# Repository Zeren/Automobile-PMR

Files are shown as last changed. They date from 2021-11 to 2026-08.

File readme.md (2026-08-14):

# SDR PMR Transceiver – Design Description (HW rev 10)

SDR transceiver for PMR446, shared channels per VO-R/16/05.2020-6 and the 70 cm amateur band. STM32H725RGV6 processes the I/Q stream from the SX1255 and generates the remodulated signal for transmit. Primary modulation is FM; SSB is a planned extension. Prepared expansion port for a CB (26.965–27.405 MHz) module on J16.

* * *

## 1. System Architecture

```
Antenna (J4 MCX) ── LPF (TX harmonics / RX pre-filter)
                  │
                  U7  (SKY13330, FILTER_TUNE, PC5) ── tune port J3
                  │
                  U10 (SKY13330, TX/RX, PC1)
                  │      RX:
                  U19 (LNA-in SW) ── U20 PGA-103+ (LNA) ── U21 (LNA-out SW)
                  │      └─────────── bypass path ───────────┘
                  U8/U9 (BPF select, RX_BAND PC4 + inverter Q4)
                  │      ├─ external BPF PMR/shared  (J12/J13, RX only)
                  │      └─ external BPF 70 cm       (J10/J11, RX only)
                  │
SX1255 (U6) ◄── I2S (Mode B2, I/Q) + SPI6 (register map) ──► STM32H725 (U15)
TAC5142 (U11 codec) ◄── I2S2 (32 bit, target/slave) ──► STM32H725 (U15)
CB module (J16) ◄── I2S3 (32 bit, master) + I2C1 + CB_nIRQ + CB_nRESET
```

TX path: STM32 (I2S1) → SX1255 (I/Q mod, synthesizer, TX front-end) → balun U5 (NCS1-521+) → π attenuator (82R/91R/91R) → PA U4 (GRF5504) → output LPF → U7/U10 switches → J4.

## 2. RF Front-End (Semtech SX1255, U6)

*   Zero-IF I/Q transceiver, internal 3 V rails VR_PA / VR_ANA1 / VR_ANA2 / VR_DIG with 1 µF decoupling each.
    
*   TX: differential RF_ON/RF_OP through balun U5 into the PA drive network. Max +7 dBm saturated.
    
*   RX: single-ended RF_IN via switch matrix and external BPF. NF typ. 4.5 dB at max LNA gain; IIP3 −23 dBm (max gain) … +20 dBm (min gain); max RF input 0 dBm operating.
    
*   Consumption: RX 18–25 mA, TX 60–90 mA from +3V3_RF.

### 2.1 Clock Domain 32 MHz

*   **TCXO1 = ATX-H13-F-32.000MHz-F25-T** (CMOS output, ±2 ppm tolerance, ±2.5 ppm over −40…+85 °C, aging ±1 ppm/yr). Worst-case error ≈ ±4.9 ppm → ±2.2 kHz @ 446 MHz. Pin 1 (EN) via R137 0R → +3V3_CLOCK (fitted); R138 0R → GND (DNP) allows Hi-Z mode for external reference operation. Powered from dedicated LDO U22 (+3V3_CLOCK).
    
*   Fanout buffer U23 (74AC04MTCX), each output with its own 30R series resistor:
    *   1Y → R130 → **J16-10** (32 MHz for the CB module),
        
    *   2Y → R132 → **PH0-OSC_IN** (MCU HSE bypass),
        
    *   3Y → R134 → **PC9** (I2S_CKIN, kernel clock of I2S1/I2S2/SPI123),
        
    *   4Y → R135 → R50/R51 1k/1k divider → **XTB** of SX1255 (~1.65 Vpp, limit 1.8 Vpp).
        
*   **External reference option (DNP group):** J17 (MMCX) → R133 50R termination → C106 → clamp D16 (BAT64) → U24 (TP74AUP1G14C5 Schmitt, DNP) → R131 → U23 inputs. For external reference mode: remove R137 (TCXO1 EN → Hi-Z) and populate the DNP group.
    
*   PLL1: 32 MHz /3 ×51 → **544 MHz** SYSCLK; HCLK 272 MHz, APB 136 MHz.
    
*   USB 48 MHz from PLL3Q: 32 MHz /6 ×90 /10 – no HSI48/CRS needed.

### 2.2 I2S1: SX1255 ↔ STM32 (Mode B2)

| Block | Parameter | Value | Note |
| --- | --- | --- | --- |
| SX1255 | I/Q mode | **Mode B2** (`IISM=10`) | I/Q multiplexed on one data line; chip is master of CLK and WS |
|  | CLK_OUT divider (`iism_clk_div`) | **48** | 32 MHz / 48 = **666.67 kHz** = BCLK |
|  | Decimation R | **1536** (MANT=8, m=1, n=6) | fs = 32 MHz / 1536 = **20.8333 kHz** |
|  | Sample width | **16 bit / channel** | frame = 32 BCLK (16 I + 16 Q) |
|  | WS output | DIO2 (pin 23) | WS=0 → I, WS=1 → Q (Philips convention) |
| STM32 I2S1 | Role | **Slave, full-duplex** | SX1255 is clock master |
|  | Standard / format | I2S Philips, **16 bit** | main.c: `I2S_MODE_SLAVE_FULLDUPLEX`, `I2S_DATAFORMAT_16B`, 20833 Hz |
|  | Kernel clock | `i2s_ckin` (PC9, 32 MHz) | RCC mux `SPI123CLKSOURCE_PIN` |

Wiring: `I_OUT` (pin 15, RX data out) → R43/R89 → **PA6** (I2S1_SDI); MCU **PA7** (I2S1_SDO) → pin 13 `I_IN` (IQ_IN in B2); `CLK_OUT` (pin 10) → R42 → **PA5** (I2S1_CK); DIO2 (WS) → R47 → **PA4** (I2S1_WS). Frequency step: FSTEP = 32 MHz / 2^20 = **30.52 Hz** (FRF registers must be recomputed for 32 MHz reference).

### 2.3 SPI6 – SX1255 Register Interface

| CubeMX parameter | Setting | Note |
| --- | --- | --- |
| Mode | Full-Duplex Master | SCK PB12… (see GPIO table), MISO PB4, MOSI PB5, SCK PC12 |
| NSS | Soft (GPIO) | **PB3** `SPI6_nCS`, held low across whole BURST transaction |
| Data / First bit | 8 bit, MSB first | per SX1255 DS |
| CPOL / CPHA | Low / 1 Edge | Mode 0 |
| Baud | **8.5 MHz** | 136 MHz APB /16; SX1255 limit ≤10 MHz |

Frame format: first byte = `wnr` (bit7, 1=write) + address A[6:0]. On read, MISO is High-Z during the address byte; on write, MISO returns the previous register content.

## 3. Baseband & DSP (STM32H725RGV6)

*   I/Q from SX1255 via I2S1 slave; **CORDIC** for phase/amplitude demodulation (Q1.15 pairs in one 32-bit WDATA word); **FMAC** for channel FIR/IIR filtering.
    
*   Core supply: internal Direct SMPS (L14 2R2 + VCAP bank), `PWR_DIRECT_SMPS_SUPPLY`, VOS0.
    
*   Firmware: C stack (HAL + STM32 USB Device Library).

## 4. Audio Chain (TAC5142IRGER, U11)

Codec on I2S2 as **target/slave** (MCU master), synchronised with the radio sampling domain. Configuration is hardware-latched on MD0–MD5 at power-up (all six pins via 0R to GND; the IOVDD side is DNP).
| Pin | Setting | Meaning |
| --- | --- | --- |
| MD0 = 0 | **Target I2S mode** | slave; BCLK/FSYNC from MCU |
| MD1/MD2 = 0/0 | AVDD 3.3 V, **32 bit**, linear-phase filters |  |
| MD3 = 0 | HPF ≈ 1 Hz, quick charge off |  |
| MD4/MD5 = 0/0 | differential AC-coupled input, differential line-out |  |

> MD pins latch at power-up; MD0 must be stable ≤2 ms after rails; changing ASI mode requires a power cycle.

### I2S2 parameters

*   Role: MCU **master** → codec target; Philips, **32 bit / 32-bit frame** (64 BCLK/frame).
    
*   fs = **20.8333 kHz**; BCLK = 32 MHz / 24 = **1.3333 MHz**; kernel = i2s_ckin.
    
*   Mapping: BCLK PB10 → U11/2; FSYNC PB12 → U11/3; MCU **PB15 (SDO) → DIN** (U11/5); codec **DOUT** (U11/4) → R57/R98 → **PB14 (SDI)**.

### Analog audio (single +30 V domain)

Audio chain U1/U12/U14 (SA5532ADR) and U13 (TPA6120A2) run on single +30 V with virtual grounds: HALF_BIAS (10k/10k divider) and HALF_BIAS_BUFFERED / HALF BIAS MIC buffered by the two halves of U14. Codec IN2 has AC coupling C57/C58 (100 nF) toward J15. Line outputs drive U12 stage → U13 (TPA6120A2, CFA, Rf = 1k, R73 = **49R9 1.5 W** series output) → C63 (**10 µF ALU 63V** DC block) → PTC F4 → J7/J8. Both TPA6120 channels powered (+LVCC/+RVCC on +30 V). Codec rails: +3V3_CODEC from U17 (LDK320).

## 5. PA Stage (GRF5504, U4)

*   Custom tune **#229 (400–500 MHz)**: gain ~40 dB, OP1dB ~33 dBm, OIP3 ~40–42 dBm, EVB NF ~5.5 dB, Iddq ~137 mA @ 5 V.
    
*   Bias resistors R37 = 3k3 (VEN1), R38 = 6k8 (VEN2) per the 5 V bias table; bias switching Q2/Q3 from PA_BIAS_ON (PC1) with external 100k pull-down.
    
*   Target operating point: **FM ≤ 33 dBm** at the connector. SSB: backoff + IMD3 measurement open (estimate −28…−30 dBc around 26 dBm/tone).

### Class-G control of the +30 V rail (TLV61047, U3)

TIM3_CH1 (PC6) PWM 25 kHz (PSC=3, ARR=2719 @ 272 MHz) is filtered (R30 91k + C29) and injected through R32 22k into the FB node. KCL at FB with VREF = 1.233 V: (VOUT − VREF)/430k + (VCTRL − VREF)/(91k + 22k) = VREF/22k → **VOUT ≈ 28.2 V @ 0 % duty … 20.4 V @ 100 % duty**, ~3 mV/LSB, linear inverse. **Firmware must clamp duty** (VREF tol. ±2 % and TPA6120/SA5532 30–33 V limits). Startup: PWM started only after rails settle.

## 6. Filters & Switch Matrix

### 6.1 Output LPF with shunt-inductor ESD protection

Series L8–L11 (19n/38n/38n/19n) + C53/C55/C56 (8p5/8p5/9p1) + **shunt inductors L12/L13 (20 nH air-core) to GND** near J4. The shunt L provides a DC/low-frequency bleed path for ESD charge instead of a diode clamp (no parasitic capacitance on the RF line; harmless at 432–450 MHz). Simulated S-parameters: **S11 < −20 dB over 432–450 MHz, IL ≤ ~0.15 dB, 2nd harmonic (860–900 MHz) −54…−58 dB**. Use air-core/wire-wound parts (no ferrite multilayer – saturation); re-tune C53 after PCB parasitics.

### 6.2 Switch truth table (SKY13330, VBATT = +3V3_RF)

| Switch | Function | CTRL (pin 7) | CTRL=1 | CTRL=0 |
| --- | --- | --- | --- | --- |
| **U10** | TX/RX path | PA_BIAS_ON (PC1) | TX (PA path) | RX |
| **U8/U9** | external BPF select | RX_BAND (PC4), inverter Q4 | 70 cm (J10/J11) | **PMR/shared (J12/J13)** |
| **U7** | antenna vs tune | FILTER_TUNE (PC5) | tune port J3 | antenna J4 |
| **U19/U21** | **LNA in/out** | **LNA ON (PC7)** | **LNA (U20) in path** | **bypass** (default after POR) |

CTRL level via 10k/22k divider ≈ **2.27 V** (valid window 1.65–2.7 V; ≤ VDD). Isolated ports are reflective-short.

### 6.3 Switchable LNA (U20 = PGA-103+)

*   Located between U10 and the BPF matrix, bypassed by U19/U21 (default bypass after POR via R123 100k pull-down on PC7).
    
*   Supply: +3V3_RF → Q8 (NX3008PBKW load switch, gate via Q9/Q10) → L16 (LQW18ANR10) + R124 1k Q-damping → U20 pin 3. Operating point ≈ 3.0–3.1 V, ~60 mA: gain ≈ 21.5 dB @ 0.4 GHz, NF ≈ 0.5 dB, P1dB ≈ +18…19 dBm, OIP3 ≈ +34 dBm.
    
*   Low-frequency stabilisation on input: C98 (100p) + L17 (330 nH) → C101 (270 pF) → R125 (120R) trap (validated in AWR; PGA-103+ is conditionally stable below ~200 MHz).
    
*   Combined RX chain NF: ~7–8 dB without LNA → ~2 dB with LNA.
    
*   **Firmware: auto-bypass by RSSI mandatory** (LNA sits before the BPF; blockers amplified). Reduce SX1255 internal LNA gain (RxLnaGain G2/G3) when external LNA active. Two RSSI calibration tables (bypass / LNA-on, ~21 dB offset).

## 7. Power Supply

| Rail | Converter | Values | Note |
| --- | --- | --- | --- |
| +26V input | J6/J7/J8, **F1 0458004.DR (4 A)**, D7 SMDJ33A | standoff 33 V | 24 V vehicle systems |
| **+5V** | U2 SIC479ED buck | 52k3/10k → 4.98 V; fSW 39k; MODE 10k; ILIMIT→VDD (4 A valley); L1 FTKB1207-6R1 | FR1 ferrite at input |
| **+30V** | U3 TLV61047 boost | 430k/22k + PWM injection (§5); L2 FTC404020S100MGCA; D4 DFLS240L | fed directly from +5 V |
| **+3V3_MCU** | U16 TLV62130 buck | 750k/240k → 3.30 V; EN=PG_5V; PG→PG_3V3; FSW=VOUT; SS 3n3; L15 2R2 | input ferrite FR3 |
| **+3V3_CODEC** | U17 LDK320 | EN=PG_5V; COUT ≈ 11 µF | ferrite FR4; codec AVDD+IOVDD |
| **+3V3_RF** | U18 LDK320 | EN=PG_5V; COUT ≈ 18 µF | ferrite FR5; SX1255 + RF switches + LNA |
| **+3V3_CLOCK** | U22 LDK320 | EN=IN (always on); COUT ≈ 13 µF | ferrite FR6; TCXO + U23 (+U24 DNP) |
| MCU core | internal SMPS | Direct SMPS, L14 2R2 + VCAP bank | PWR_DIRECT_SMPS_SUPPLY |

*   All ferrites: 742792023 (120 Ω @100 MHz, 3 A). Local ceramics at each IC per its layout guide.
    
*   Sequencing: SIC479 PGOOD → enables U3/U16/U17/U18 (PG_5V); TLV62130 PG → PG_3V3 (LED).
    
*   J16 carries **+POWER_RAIL** (26 V behind F1/TVS/FR2) with C101 = 10 µF ALU at the header.

## 8. USB (OTG HS, FS embedded PHY)

Composite device: Audio Control, AS OUT (playback, async + feedback), AS IN (record / I/Q), CDC (CAT). VBUS sensing PA9 via 10k/39k divider. USB clock: PLL3Q 48 MHz.
**Asynchronous UAC at 20.833 kHz:** declared 24 kHz nominal rate would be wrong — device works with **mostly 21 samples, sometimes 20 samples per 1 ms SOF** (average 20.833) on the IN endpoint; host-side async resampling handles the rest (same mechanism as before, recalculated for 32 MHz).

## 9. MCU Configuration (CubeMX rev)

*   PLL: HSE_BYPASS 32 MHz → M=3, N=51, P=1 → 544 MHz; HCLK 272, APB 136 MHz.
    
*   I2S1 slave FD 16 bit 20833 Hz; I2S2 master FD 32 bit; I2S3 master FD 32 bit (CB, J16).
    
*   SPI6 /16 → 8.5 MHz; kernel SPI123 = i2s_ckin (RCC mux `RCC_SPI123CLKSOURCE_PIN`).
    
*   I2C1 timing 0xA0303048 (~100 kHz @136 MHz) – external buses J15/J16.
    
*   TIM3 CH1 PC6 PWM 25 kHz for class-G; UART4 (panel), UART5 (debug: TX PB13, RX PD2).
    
*   USB: PLL3Q 48 MHz; FS embedded PHY, VBUS sensing.
    
*   Debug: **Serial Wire only** (JTAG pins reused).
    
*   Verify in generated MSP: `HAL_RCCEx_PeriphCLKConfig()` with PLL3 = 32/6/90/Q=10 for USB and SPI123 kernel = pin clock.

### GPIO map

| Signal | Pin | Type | Function |
| --- | --- | --- | --- |
| RADIO_RESET | PC0 | In/Out | SX1255 reset (OD emulation: PP high 100 µs → Hi-Z, 5 ms wait) |
| **PA_BIAS_ON** | PC1 | Out PP | 1 = TX (PA bias + U10 switch); 100k ext pull-down |
| **RX_BAND** | PC4 | Out PP | 0 = PMR/shared BPF (J12/J13), 1 = 70 cm BPF (J10/J11) |
| **FILTER_TUNE** | PC5 | Out PP | 1 = tune port J3 instead of antenna |
| **LNA ON** | PC7 | Out PP | 1 = LNA in path; 0 = bypass (POR default) |
| **MCU 30V CTRL** | PC6 | AF (TIM3_CH1) | class-G PWM 25 kHz |
| PTT_TO_MCU | PA2 | In (pull-up) | 0 = TX; debounce in FW |
| PTT_LED | PA3 | Out PP | red TX LED |
| **SPI6_nCS** | PB3 | Out PP | SX1255 NSS (manual, across BURST) |
| **CB_nIRQ** | PB8 | In EXTI falling, pull-up | CB module interrupt |
| **CB_nRESET** | PB9 | Out PP, init HIGH | CB module reset |
| I2S_CKIN | PC9 | AF input | 32 MHz kernel clock |
| SWDIO/SWCLK | PA13/PA14 | AF | programming via J5 |
| UART4 TX/RX | PA0/PA1 | AF | control panel |
| UART5 TX/RX | PB13/PD2 | AF | debug console (J5) |

## 10. Connectors

**J5 – service (53047-1010):** 1 SWDIO, 2 SWCLK, 3 NRST, 4 UART_DEBUG_TX, 5 UART_DEBUG_RX, 6 I2C_SCL, 7 I2C_SDA, 8 +5V, 9 +3V3, 10 GND.
**J16 – CB module (61301621121):** 1/2/11/12 GND, 3 I2S3_CLK, 4 I2C_SCL, 5 I2S3_DIN, 6 I2C_SDA, 7 I2S3_DOUT, 8 +5V, 9 I2S3_WS, **10 = 32 MHz clock out**, 13 CB_nIRQ, 14/16 +POWER_RAIL (26 V), 15 CB_nRESET.
**RF:** J4 antenna MCX; J3 tune port MMCX; J10/J11 external BPF 70 cm; J12/J13 external BPF PMR/shared; J17 external 32 MHz reference input (DNP option); J2 UFL (test).

### M12 connector

| M12 | Function | Wire color |
| --- | --- | --- |
| 1 | +26V | Black |
| 2 | PTT | Brown |
| 3 | Mic+ | Red |
| 4 | Mic- | Orange |
| 5 | NC | Yellow |
| 6 | Speaker | Green |
| 7 | GND | Blue |
| 8 | NC | Violet |

### R123

| Cont. |  | Cont. |  | Cont. |  |
| --- | --- | --- | --- | --- | --- |
| a1 |  | b1 | +26V (Black) | c1 |  |
| a2 |  | b2 |  | c2 | GND (Blue) |
| a3–a8 |  | b3–b9 |  | c3–c8 |  |
| a9 |  | b9 |  | c9 | PTT (Brown) |
| a0 | Speaker (Green) | b0 | MIC+ (Red) | c0 | MIC- (Orange) |

### R124 A-2

| Cont. |  | Cont. |  |
| --- | --- | --- | --- |
| a1 | A-1 R112 MIC+ | b1 | A-1 R123 MIC+ |
| a2 | A-1 R112 MIC- | b2 | A-1 R123 MIC- |
| a3 | Tangenta PTT | b3 | Tangenta MIC+ |
| a4 | Intercom MIC to PA | b4 | Tangenta MIC- |
| a5 | GND | b5 | A-1 R112 Speaker |
| a6 | +22V for A-2..A-5 | b6 | A-1 R112 PTT |
| a7 | Tangenta Speaker | b7 | A-1 R123 Speaker |
| a8 | Intercom Speaker | b8 | A-1 R123 PTT |

## PMR 446 Technical Specification

*   Transmit Power 500 mW ERP
    
*   Bandwidth 12.5 kHz
    
*   Antenna fixed, non removable
    
*   Frequency Modulation and digital modes
    
*   User Separation CTCSS, DCS, digital signalling
    
*   Frequencies (Simplex TX=RX)

## 11. Open Items / Bench Checklist

1.  Verify amplitudes after assembly: ~3.3 Vpp CMOS at U23 inputs, ~1.65 Vpp at XTB (U6-8).
    
2.  External reference mode (if used): input at U24 must provide ≥ ~1.6 Vpp to clear the TP74AUP1G14C5 thresholds; rework = remove R137, populate U24 + J17/R133/D16 group.
    
3.  SSB: measure GRF5504 IMD3 on the devboard, set operating backoff.
    
4.  PMR446 "fixed antenna" requirement vs J4 connector – documentation decision.
    
5.  MICBIAS (U11-14) unused with dynamic microphone – leave with local 1 µF only.
    
6.  AWR re-check of LPF with real air-coil models (DCR/SRF) and sweep to ≥1.4 GHz (3rd harmonic).
    
7.  LNA stability/NF verification with the complete RX cascade on the prototype.

## Layout Checklist (for the frozen schematic)

*   GRF5504 power pad: multiple 8-mil vias per eval board guidance; TPA6120 PowerPAD soldered with vias; TAC5142 thermal pad grounded; SKY13330 exposed pads low-impedance GND.
    
*   SIC479 input/PGND loops, BOOT cap placement, AGND single-point, TLV61047 SW node minimal, TLV62130 VOS tapped at C_out.
    
*   LDO input/output caps at pins (COUT ≤ 22 µF per rail), ferrites directly in input paths.
    
*   Clock domain (TCXO1 → R136 → U23 → fanout) short, away from USB D±, audio and J16/J17; no 32 MHz trace over GND plane splits.
    
*   +26V/fuse/ESD at board edge near J6–J8; J16 +26V branch traces sized ≥3 A.

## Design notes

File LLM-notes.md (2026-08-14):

# How to get HW specification

Proveď destilaci celého našeho návrhu hardwaru a vygeneruj strojově čitelný "Hardware Specification Manifest" ve formátu YAML. Udělej ho jako raw, nebo jako přílohu (attachment).
Tento dokument bude sloužit jako jediný vstup pro vývoj embedded firmwaru. Zcela ignoruj proces návrhu, BOM, pasivní součástky (pokud neovlivňují logiku) a fyzický layout. Soustřeď se výhradně na to, co musí znát programátor (C, STM HAL). Ještě můžeš doporučit nastavení DMA kanálů (především I2S, SPI, UART). Potom je ještě zvlášť napiš jaké mám kde nastavit v SMT32cubeMX.
Při generování dodržuj tuto strukturu:
1. mcu_config: Přesný typ MCU, frekvence jádra, zdroj hodin (HSE/HSI).
2. pinmap: Seznam všech využitých pinů. Formát: [Pin, Název signálu, Směr/Typ, Pull-up/down, Alternate Function (pokud jde např. o STM32 AF), Aktivní úroveň (High/Low)].
3. peripherals: Konfigurace periferií (např. I2C adresy slave zařízení na sběrnici, rychlost SPI, baudrate UARTu, přiřazení DMA kanálů).
4. power_and_reset: Sekvence zapínání periferií (pokud existují povolovací EN piny), časy potřebné pro ustálení napětí, konfigurace externího watchdogu.
5. interrupts: Požadovaná hardwarová přerušení a jejich priority.
6. quirks: Hardwarová specifika (např. "LED svítí při log. 0", "Senzor XY vyžaduje po startu 10 ms delay", "CS pin pro SPI flash má externí pull-up").
Vrať POUZE čistý kód ve formátu YAML. Nepřidávej žádný úvodní ani závěrečný text, žádné vysvětlování. Výstup bude anglicky.

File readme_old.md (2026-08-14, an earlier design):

# PMR radio for R124

# Connection to R124

## Connection in R124 A-1
### Connection as R112. 

| Cont. | | Cont. | | Cont. | |
|---|---|---|---|---|---|
| a1 | | b1 | +26V <br/> Black | c1 | |
| a2 | | b2 | Speaker <br/> Green | c2 | GND <br/> Blue |
| a3 | PTT<br/> Brown | b3 | MIC- <br/>Orange | c3 | MIC+ <br/> Red |
| a4 | | b4 | | c4 | |
| a5 | | b5 | | c5 | |
| a6 | | b6 | | c6 | |
| a7 | | b7 | | c7 | |
| a8 | | b8 | | c8 | |
| a9 | | b9 | | c9 | |
| a0 | | b0 | | c0 | |

### Connection as R123. 

| Cont. | | Cont. | | Cont. | |
|---|---|---|---|---|---|
| a1 | | b1 | +26V <br/> Black | c1 | |
| a2 | | b2 | | c2 | GND <br/> Blue |
| a3 | | b3 | | c3 | |
| a4 | | b4 | | c4 | |
| a5 | | b5 | | c5 | |
| a6 | | b6 | | c6 | |
| a7 | | b7 | | c7 | |
| a8 | | b8 | | c8 | |
| a9 | | b9 | | c9 | PTT<br/> Brown |
| a0 | Speaker <br/> Green | b0 | MIC+ <br/> Red | c0 | MIC- <br/>Orange |

## M12 Connector

| M12 | Function | Wire color |
|-----|---|---|
| 1 | +26V | Black |
| 2 | PTT | Brown |
| 3 | Mic+ | Red |
| 4 | Mic- | Orange |
| 5 | NC | Yellow |
| 6 | Speaker  | Green |
| 7 | GND | Blue |
| 8 | NC | Violet |

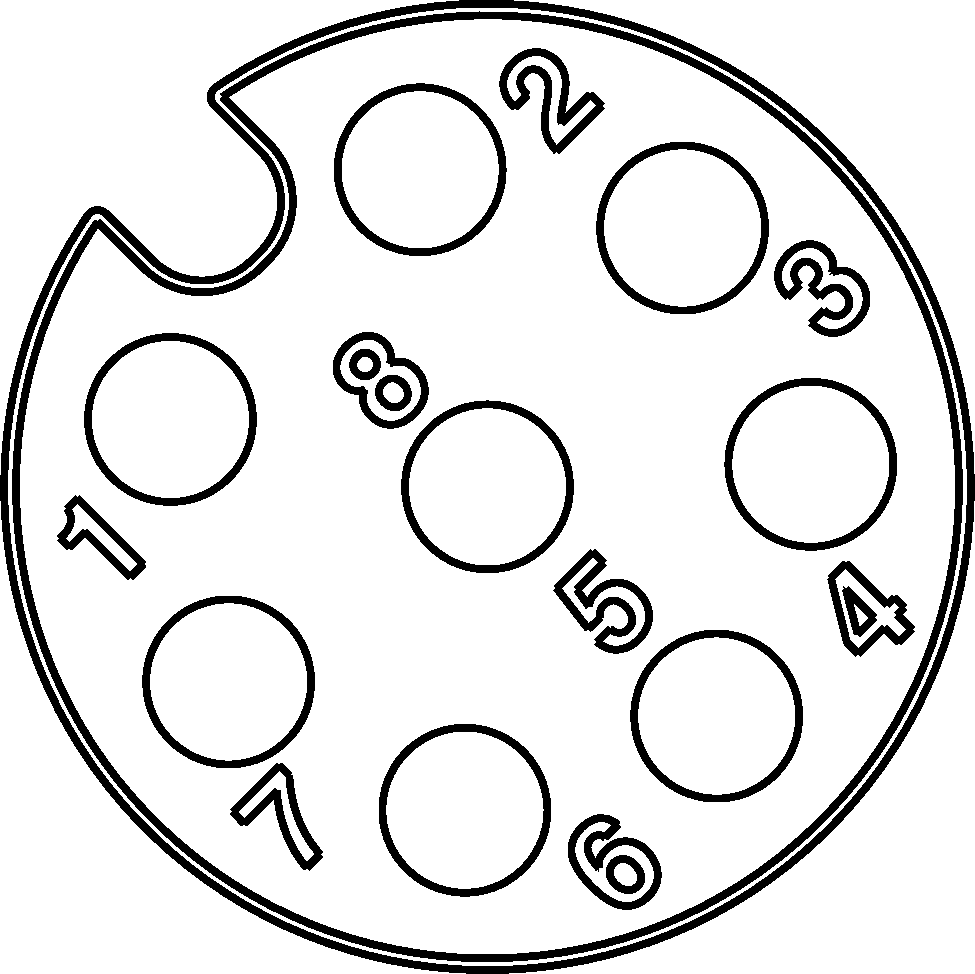
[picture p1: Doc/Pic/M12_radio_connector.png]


## Updates for v2

- Add resistors to feedback of speaker amplifier to add gain
- Lower values of resistors in feedback of mic amplifier to make it stable
- Lower gain of mic amplifier
- Add connection for BT audio input/output for hands free
  - Make it as module to 2.54mm  pin header
  - ESP32 and ES8388 look like good choice

# PMR 446 Technical Specification

- Transmit Power 500mW Estimated (REP)
- Bandwidth 12.5kHz 
- Antenna Fixed, non removable. Impossible to connect to external aerial.
- Frequency Modulation and digital modes.
- User Separation CTCSS, DCS, digital signalling.
- Frequencies (Simplex TX=RX)

## Channels

| Category | Channel | Frequency [MHz] | Max. Allowed Power | Bandwidth / Note |
| --- | --- | --- | --- | --- |
| **PMR (UHF)** | 1 | 446.00625 | 500 mW |  |
|  | 2 | 446.01875 | 500 mW |  |
|  | 3 | 446.03125 | 500 mW |  |
|  | 4 | 446.04375 | 500 mW |  |
|  | 5 | 446.05625 | 500 mW |  |
|  | 6 | 446.06875 | 500 mW |  |
|  | 7 | 446.08125 | 500 mW |  |
|  | 8 | 446.09375 | 500 mW |  |
|  | 9 | 446.10625 | 500 mW |  |
|  | 10 | 446.11875 | 500 mW |  |
|  | 11 | 446.13125 | 500 mW |  |
|  | 12 | 446.14375 | 500 mW |  |
|  | 13 | 446.15625 | 500 mW |  |
|  | 14 | 446.16875 | 500 mW |  |
|  | 15 | 446.18125 | 500 mW |  |
|  | 16 | 446.19375 | 500 mW |  |
| **Shared (VHF)** | 1 | 172.650 | 5 W | 10 kHz |
|  | 2 | 172.725 | 1 W | 10 kHz |
|  | 3 | 172.950 | 5 W | 10 kHz |
|  | 4 | 172.975 | 5 W | 10 kHz |
|  | 5 | 173.050 | 1 W | 10 kHz |
| **Shared (UHF)** | 1 | 448.490 | 5 W | 14 kHz |
|  | 2 | 448.570 | 5 W | 14 kHz |
|  | 3 | 448.610 | 5 W | 14 kHz |
|  | 4 | 449.770 | 1 W | 14 kHz |
|  | 5 | 449.810 | 1 W | 14 kHz |
|  | 6 | 442.200 | 5 W | 16 kHz |
|  | 7 | 442.225 | 5 W | 16 kHz |
|  | 8 | 442.250 | 5 W | 16 kHz |
|  | 9 | 442.275 | 5 W | 16 kHz |
| **CB Band** | 1 | 26.965 | 4 W (FM/AM), 12 W (SSB) |  |
|  | 2 | 26.975 | 4 W (FM/AM), 12 W (SSB) |  |
|  | 3 | 26.985 | 4 W (FM/AM), 12 W (SSB) |  |
|  | 4 | 27.005 | 4 W (FM/AM), 12 W (SSB) |  |
|  | 5 | 27.015 | 4 W (FM/AM), 12 W (SSB) |  |
|  | 6 | 27.025 | 4 W (FM/AM), 12 W (SSB) |  |
|  | 7 | 27.035 | 4 W (FM/AM), 12 W (SSB) |  |
|  | 8 | 27.055 | 4 W (FM/AM), 12 W (SSB) |  |
|  | 9 | 27.065 | 4 W (FM/AM), 12 W (SSB) |  |
|  | 10 | 27.075 | 4 W (FM/AM), 12 W (SSB) |  |
|  | 11 | 27.085 | 4 W (FM/AM), 12 W (SSB) |  |
|  | 12 | 27.105 | 4 W (FM/AM), 12 W (SSB) |  |
|  | 13 | 27.115 | 4 W (FM/AM), 12 W (SSB) |  |
|  | 14 | 27.125 | 4 W (FM/AM), 12 W (SSB) |  |
|  | 15 | 27.135 | 4 W (FM/AM), 12 W (SSB) |  |
|  | 16 | 27.155 | 4 W (FM/AM), 12 W (SSB) |  |
| **Other Shared** | - | 34.050 | 1 W |  |
|  | - | 34.075 | 1 W |  |
|  | - | 34.150 | 1 W |  |
|  | - | 34.175 | 1 W |  |
|  | - | 77.025 | 1 W |  |
|  | - | 77.050 | 1 W |  |
|  | - | 77.075 | 1 W |  |
|  | - | 77.100 | 1 W |  |
|  | - | 77.725 | 1 W |  |
|  | - | 78.000 | 1 W |  |
|  | - | 81.725 | 1 W |  |
|  | - | 81.750 | 1 W |  |

## CTCSS Codes

| Code | Tone [Hz] | Code | Tone [Hz] | Code | Tone [Hz] |
| --- | --- | --- | --- | --- | --- |
| 0 | Off | 13 | 103.5 | 26 | 162.2 |
| 1 | 67.0 | 14 | 107.2 | 27 | 167.9 |
| 2 | 71.9 | 15 | 110.9 | 28 | 173.8 |
| 3 | 74.4 | 16 | 114.8 | 29 | 179.9 |
| 4 | 77.0 | 17 | 118.8 | 30 | 186.2 |
| 5 | 79.7 | 18 | 123.0 | 31 | 192.8 |
| 6 | 82.5 | 19 | 127.3 | 32 | 203.5 |
| 7 | 85.4 | 20 | 131.8 | 33 | 210.7 |
| 8 | 88.5 | 21 | 136.5 | 34 | 218.1 |
| 9 | 91.5 | 22 | 141.3 | 35 | 225.7 |
| 10 | 94.8 | 23 | 146.2 | 36 | 233.6 |
| 11 | 97.4 | 24 | 151.4 | 37 | 241.8 |
| 12 | 100.0 | 25 | 156.7 | 38 | 250.3 |

# R124 Notes

## Connectors

### R124 A-1

| Cont. | | Cont. | | Cont. | |
|---|---|---|---|---|---|
| a1 | NC | b1 | +26V | c1 | NC |
| a2 | NC | b2 | R112 Speaker | c2 | GND |
| a3 | R112 PTT | b3 | R112 MIC- | c3 | MIC+ |
| a4 | A-2 R112 Speaker | b4 | A-2 R123 MIC+ | c4 | A-2 R112 MIC+ |
| a5 | A-2 R123 Speaker | b5 | A-2 R123 MIC- | c5 | A-2 R112 MIC- |
| a6 | Tangenta Speaker | b6 | Tangenta Intercom PB | c6 | Tangenta GND  |
| a7 | Tangenta MIC+ | b7 | Tangenta MIC- | c7 | Tangenta PTT  |
| a8 | Intercom Speaker for <br/>A-2, A-3, A-4, A-5 | b8 | Intercom PB | c8 | GND |
| a9 | +22V for <br/>A-2, A-3, A-4, A-5 | b9 | Intercom MIC to PA | c9 | R123 PTT |
| a0 | R123 Speaker | b0 | R123 MIC+ | c0 | R123 MIC- |

Intercom MIC to PA - Amplified microphone

### R124 A-2

| Cont. | | Cont. | | 
|---|---|---|---|
| a1 | A-1 R112 MIC+ | b1 | A-1 R123 MIC+ |
| a2 | A-1 R112 MIC- | b2 | A-1 R123 MIC- |
| a3 | Tangenta PTT | b3 | Tangenta MIC+ |
| a4 | Intercom MIC to PA | b4 | Tangenta MIC- |
| a5 | GND | b5 | A-1 R112 Speaker |
| a6 | +22V for <br/>A-2, A-3, A-4, A-5 | b6 | A-1 R112 PTT |
| a7 | Tangenta Speaker | b7 | A-1 R123 Speaker |
| a8 | Intercom Speaker | b8 | A-1 R123 PTT |

# Architektura SDR Transceiveru

## 1. Hodinová synchronizační doména (Clock Tree)

* **Hlavní oscilátor:** Společné 36MHz TCXO pro celou desku.
* **Distribuce signálu (Hardware Split):**
* Větev pro mikrokontrolér vedena přímo do vstupu `OSC_IN` s plnou logickou úrovní.
* Větev pro RF front-end vedena do vstupu `XTB` přes tlumicí člen (např. odporový dělič s AC vazbou), aby nebyla překročena maximální povolená špičková úroveň 1.8 Vpp. Vstup `XTA` zůstává nezapojený.

* **Zpracování beze skluzu:** Všechny vzorkovací frekvence v systému (I/Q data i audio) jsou odvozeny čistým celočíselným dělením z 36 MHz. Tím je zcela eliminována nutnost použití asynchronního převzorkování (ASRC) nebo zlomkových PLL.

## 2. RF Front-End (Semtech SX1255)

* **Architektura:** Zero-IF transceiver.

* **Digitální rozhraní:** Využit integrovaný Digital Bridge v režimu **Mode B2** (I2S kompatibilní datový tok, multiplexované I a Q signály na jednom pinu).

* **Decimace na čipu:** Nastavena na hodnotu **1536** pomocí 1. sady parametrů ($\text{MANT}=8$).

* **Vzorkovací frekvence (I/Q):** Odvozena z krystalu na $23.4375\text{ kHz}$.

* **Formát rámce:** Parametr `CLK_OUT/XTAL` nastaven na dělení 24. Výstupní hodiny $f_{CLK\_OUT}$ běží na $1.5\text{ MHz}$, což generuje standardní I2S rámec o délce 64 pulzů (32 bitů na složku). Do DMA mikrokontroléru se ukládá pouze 16 bitů (poskytujících dynamický rozsah cca $98\text{ dB}$).

## 3. Baseband a DSP (STM32H725RGV6)

* **Sběr rozhraní:** Vyčítání SX1255 probíhá přes standardní I2S (nebo SAI) periferii v režimu Master. MCU generuje BCLK a WS.
* **Matematická koprocese:**
* **CORDIC:** Využit pro hardwarově akcelerovanou fázovou a amplitudovou demodulaci. Vstupní 16bitová data (formát Q1.15) z DMA se prokládají do jediného 32bitového slova pro zápis do `WDATA` registru koprocesoru.

* **FMAC:** K dispozici jako Filter Mathematical Accelerator pro dodatečné rychlé kanálové FIR/IIR filtrování před samotnou demodulací.

* **Firmware:** Napsán v jazyce Rust nad asynchronním frameworkem Embassy (využívající `embassy-stm32` a `embassy-executor`), což umožňuje bezblokující řízení I2S DMA přeskoků.

## 4. Audio Front-End a koncový stupeň

* **Audio Kodek:** TAC5142 v režimu Slave. BCLK a WS generuje STM32H7. Vzorkovací frekvence audia je buď nativních $23.4375\text{ kHz}$, nebo po jedné decimaci/half-band filtru $11.71875\text{ kHz}$.
* **Mikrofonní vstup:** Sovětské uhlíkové vložky nahrazeny moderními elektretovými nebo dynamickými kapslemi. Předpětí (bias) je řešeno standardně přes vývod `MICBIAS` kodeku TAC5142 s vazbou do diferenciálního vstupu PGA.
* **Audio koncový stupeň:** Zesilovač TPA6120A2 řídící sluchátka v sovětské tankistické kukle.
* **Napájení:** Asymetrické (až 30 V) z dedikovaného step-up DC/DC měniče (vstup 5 V). Výstupní napětí z měniče bude možné dynamicky řídit (princip třídy G/H) pro maximalizaci účinnosti PA na základě reálného rozkmitu.
* **Virtuální střed:** Realizován ratiometrickým odporovým děličem z DC/DC napájení, který je posílen přes volný operační zesilovač v zapojení napěťového sledovače. Toto zajišťuje tvrdý střed s nízkou výstupní impedancí (odstranění přechodových subsonických rázů a přeslechů).
* **Specifika CFA topologie:** TPA6120A2 je zesilovač s proudovou zpětnou vazbou. Zpětnovazební rezistor $R_f$ má fixní hodnotu $1\text{ k}\Omega$ a absolutně se vynechává jakákoliv kapacita v paralelní zpětnovazební větvi. Na DPS je striktně odstraněn měděný polygon pod piny invertujících vstupů (IN-). Výstup je oddělen sériovým blokovacím DC kondenzátorem $220\ \mu\text{F}$.

## 5. RF Koncový stupeň (Transmitter PA)

* **Výkonový stupeň:** InGaP HBT tranzistor Guerrilla RF GRF5504 vybuzený na kompresní hranu, dodávající na konektor výkon $34.8\text{ dBm}$ (zhruba $3\text{ W}$), což je ideální pro sdílené kmitočty v ČR ($448\text{ MHz} / 449\text{ MHz}$).
* **Výstupní filtrace:** Modifikovaný dolní propust (LC Čebyšev), kde jsou nuly přenosu (LC pasti) úmyslně a přesně naladěny na eliminaci 2. a 3. (případně 4.) harmonické. Tím je dosaženo extrémní strmosti přesně v pásmech, kam by komprimující GRF5504 produkoval největší intermodulační rušení, při zachování minimálního vložného útlumu v propustném pásmu.

## 6. Uživatelské a ladicí rozhraní (HMI & Debug)

* **Externí ovládací panel:** Volitelné příslušenství. Připojení je realizováno asynchronně přes sériovou linku **UART4**. Panel není nezbytný pro základní chod transceiveru (jádro SDR může běžet zcela autonomně).
* **Debug a programování:** Sdružený servisní konektor.
  * **Diagnostická konzole:** Linka **UART7** je vyhrazena výhradně pro výpis běhových logů (např. logování z asynchronních úloh v Embassy) a interní diagnostiku.
  * **Programovací rozhraní:** Využity standardní signály **SWDIO** a **SWCLK** pro flashování firmwaru a on-chip debugging.

## Parametry pro I2S propojení (SX1255 $\leftrightarrow$ STM32H725)

| Architektonický blok | Parametr | Hodnota / Nastavení | Popis a výpočet |
|---|---|---|---|
| **Hodinová doména** | Základní takt krystalu (XTAL) | **36 MHz** | Společný fyzický krystal pro MCU i SX1255. |
| **SX1255: Digital Bridge**  | Provozní režim I/Q | **Mode B2** | Plně I2S kompatibilní. I a Q složky jsou multiplexovány na jedné datové lince. |
| | Sada parametrů (MANT) | **8** (1st set) | V registru `0x13` bit `int_dec_mantisse = 0`. |
| | Parametr $m$ | **1** | V registru `0x13` bit `int_dec_m_parameter = 1`. |
| | Parametr $n$ | **6** | V registru `0x13` bity `int_dec_n_parameter = 6`. |
| | **Celková decimace** ($R$) | **1536** | Vzorec: $R = 8 \times 3^1 \times 2^6 = 1536$. |
| | Dělička výstupních hodin | **48** | V registru `0x12` bity `iism_clk_div = 1000`. Dělí XTAL pro získání bitových hodin (BCLK). |
| **SX1255: I2S Výstup** | Vzorkovací frekvence ($f_s$) | **23.4375 kHz** | $36\text{ MHz} / 1536 = 23.4375\text{ kHz}$. |
| | Frekvence hodin ($f_{CLK\_OUT}$) | **750 kHz** | $36\text{ MHz} / 48 = 750\text{ kHz}$. Toto je sériový Bit Clock (BCLK). |
| | Rozlišení vzorku (Data Size) | **16 bitů** | Pro děličku 48 a decimaci 1536 generuje čip nativně 16 bitů na kanál. |
| | Počet pulzů na rámec (Frame) | **32 bitů** | 16 bitů (I) + 16 bitů (Q). Zkouška: $750\text{ kHz} / 32 = 23.4375\text{ kHz}$. |
| **STM32CubeMX (I2S / SAI)** | Role na sběrnici | **Slave** | **Klíčové:** V módu B je SX1255 vždy Master a generuje hodiny i Word Select. |
| | Standard protokolu | **I2S Philips** | Word Select (WS) o 1 takt předchází datům, což přesně odpovídá logice Mode B v SX1255. |
| | Data Format / Data Size | **16 Bits Data on 16 Bits Frame** | Pro každý z obou kanálů (I i Q). Tím MCU očekává přesně 32 hodinových cyklů na jeden WS rámec. |
| | Audio Frequency | **23.4375 kHz** | Odpovídá našemu výpočtu (v CubeMX se v režimu Slave většinou dopočítá z BCLK, ale je dobré to mít na zřeteli). |
| | Mapování pinů (Příjem z RX) | **BCLK:** `CLK_OUT`<br><br>**WS:** `DIO2`<br><br>**SD_RX:** `I_IN` | Fyzické propojení signálů pro příjem. (Pro vysílání se z MCU použije `SD_TX` do `I_OUT`). |

### Důležité poznámky pro realizaci a CubeMX:

1. **STM32 jako Slave:** Přestože mikrokontrolér STM32H7 bude řídit celou logiku, z pohledu této konkrétní datové sběrnice (přenos I/Q dat) musí být jeho I2S/SAI nastaveno jako **Slave**. SX1255 si sám časuje vyhazování dat pomocí svého interního děliče hodin.

2. **Polarita Word Select (WS):** Protokol SX1255 (Mode B2) určuje, že když je WS na logické "0", přenáší se I (In-phase) složka, a při logické "1" se přenáší Q (Quadrature) složka. Standardní I2S Philips v STM32 funguje přesně takto (levý kanál na nule, pravý na jedničce), takže se ti I a Q složky namapují naprosto korektně a stabilně do levého a pravého kanálu v DMA bufferu.

## Konfigurace I2S a vnitřních bloků (STM32H725 $\leftrightarrow$ TAC5142)

| Architektonický blok | Parametr | Hodnota / Nastavení | Popis a výpočet |
|---|---|---|---|
| **TAC5142: Hardware Control** | `MD0` (Režim a Rozhraní) | **0 (GND)** | **Target I2S Mode**. TAC5142 je Slave, očekává BCLK a FSYNC z mikrokontroléru. |
| | `MD1` a `MD2` (Audio formát) | **0 (GND) / 0 (GND)** | AVDD = 3.3 V, délka slova = **32 bitů**, Linear-phase filtr. |
| | `MD3` (HPF a Quick Charge) | **0 (GND)** | **HPF Cut-off = 1 Hz** (@ 48 kHz). Input Cap Quick Charge = Disabled (50 ms). |
| | `MD4` a `MD5` (Analog I/O) | **0 (GND) / 0 (GND)** | **Vstup:** Diferenciální, AC-vazba.<br><br>**Výstup:** Diferenciální, Line-out. |
| **Hodinová doména (Z MCU)** | Vzorkovací frekvence ($f_s$) | **23.4375 kHz** | Určena signálem FSYNC (Word Select) generovaným z MCU, fázově svázáno s SX1255. |
| | Frekvence Bit Clock (BCLK) | **1.5 MHz** | Pro 32bitový I2S rámec: $23.4375\text{ kHz} \times (32\text{ bitů} \times 2\text{ kanály}) = 1.5\text{ MHz}$. MCU musí přesně toto generovat. |
| | Poměr BCLK / FSYNC | **64** | Očekáváno v Target I2S Mode pro 32bitové slovo na levý i pravý kanál ($32 + 32 = 64$). |
| **STM32CubeMX (I2S / SAI)** | Role na sběrnici | **Master** | MCU musí generovat BCLK a WS (FSYNC) pro TAC5142. |
| | Standard protokolu | **I2S Philips** | Odpovídá Target I2S Mode na TAC5142. |
| | Data Format / Data Size | **32 Bits Data on 32 Bits Frame** | Zajišťuje vygenerování 64 BCLK pulzů na jeden FSYNC rámec. |
| | Audio Frequency | **23.4375 kHz** | Cílová vzorkovací frekvence, ze které MCU přes interní děličku odvodí BCLK. |
| | Mapování pinů | **BCLK:** `BCLK`<br><br>**WS:** `FSYNC`<br><br>**SD_RX:** `DOUT`<br><br>**SD_TX:** `DIN` | Fyzické propojení signálů pro obousměrný přenos audia. |

Pro správnou komunikaci s RF front-endem SX1255 je nutné SPI3 nakonfigurovat podle specifikací v katalogovém listu. Digitální rozhraní SX1255 je plně synchronní a podporuje jak izolovaný přístup (SINGLE), tak blokový přenos (BURST) s automatickou inkrementací adresy.

Zde je kompletní přehled nastavení pro STM32CubeMX:

## Konfigurace SPI3 pro SX1255

| Parametr v STM32CubeMX | Nastavení / Hodnota | Popis a hardwarová specifikace SX1255 |
|---|---|---|
| **Mode** | **Full-Duplex Master** | Klasická čtyřvodičová topologie (MOSI, MISO, SCK a CS/NSS). |
| **Hardware NSS Signal** | **Disable** *(doporučeno)* | Přestože lze použít hardwarový NSS, pro BURST přístup do registrů je nezbytné řídit NSS (Chip Select) softwarově přes standardní GPIO (Output Push-Pull). V BURST režimu totiž musí NSS zůstat v logické `0` nepřetržitě mezi jednotlivými datovými bajty a do logické `1` přejít až po ukončení celé transakce. |
| **Frame Format** | **Motorola** | Standardní topologie specifikovaná výrobcem. |
| **Data Size** | **8 Bits** | Adresování i datové toky jsou striktně 8bitové. |
| **First Bit** | **MSB First** | Nejdůležitější bit (Most Significant Bit) je vždy přenášen jako první. |
| **Clock Polarity (CPOL)** | **Low** | V klidovém stavu (idle) je hodinový signál SCK na úrovni logické `0`. |
| **Clock Phase (CPHA)** | **1 Edge** | Vstupní data (MOSI u Slave, MISO u Master) jsou vzorkována na první, tedy náběžné (rising) hraně SCK. Data na výstupu se mění s týlovou (falling) hranou. |
| **Baud Rate Prescaler** | Zvolit tak, aby $f_{SCK} \le$ **10 MHz** | Absolutní maximální frekvence hodin SCK pro sběrnici SX1255 je 10 MHz. Pro jádro STM32H7 běžící na vysokých frekvencích budeš muset nastavit poměrně vysoký dělící poměr na příslušné APB sběrnici. |

### Skladba přenosového rámce (Frame Structure)

Během implementace SPI ovladačů do firmwaru je třeba počítat se specifickým formátem prvního (adresního) bajtu, který mikrokontrolér posílá směrem do SX1255:

* **Bit 7 (`wnr`):** Určuje směr toku dat. Logická `1` pro zápis (Write), logická `0` pro čtení (Read).

* **Bity 6 až 0 (`A[6:0]`):** Fyzická adresa registru.

Při čtecí operaci (Read) vysílá SX1255 během odesílání adresního bajtu na lince MISO vysokou impedanci (High-Z) a samotná data začne posílat až s prvním bitem druhého bajtu (taktovaným od SCK). Při zápisu (Write) kopíruje SX1255 na MISO linku předchozí obsah zapisovaného registru (stav před samotným přepsáním).

### Kritické časovací parametry pro firmware

Pokud bys pro obsluhu SPI nevyužíval standardní blokovací HAL funkce a přistupoval bys k registrům velmi těsně napřímo (např. bit-banging NSS pinu bezprostředně kolem startu DMA), dej si pozor na tyto katalgové limity:

* **$t_{nsetup}$ (NSS set-up time):** Minimálně **30 ns** od pádu NSS do první náběžné hrany SCK.
* **$t_{nhold}$ (NSS hold time):** Minimálně **50 ns** od poslední týlové hrany SCK do zvednutí NSS zpět do logické `1`.
* **$t_{nhigh}$ (NSS high time):** Minimálně **20 ns** odpočinek (High stav NSS) mezi dvěma nezávislými SPI transakcemi.

---

# Architektura USB rozhraní (Composite UAC 1.0 + CDC)

## 1. Topologie a hardwarová vrstva

* **Periferie:** `USB_OTG_HS` s integrovaným Full-Speed PHY (rychlost 12 Mbit/s).
* **Napájení:** Self-Powered (zařízení napájeno vlastním zdrojem).
* **Detekce připojení:** VBUS sensing povolen na vyhrazeném pinu (bude nutný odporový dělič z 5 V linky USB kabelu na bezpečné 3.3 V pro MCU).
* **Přenos dat:** Vyhrazené interní DMA pro `USB_OTG_HS` (zcela odbřemení CPU jádra Cortex-M7 od přesunu dat do/z USB FIFO paměti).
* **Start of Frame (SOF):** Povoleno softwarové přerušení na SOF (1 ms interval) pro kritickou synchronizaci audio bufferů.

## 2. Kompozitní konfigurace (USB Descriptors)

Zařízení se po připojení k PC enumeruje s jedním USB Configuration Descriptorem, který bude obsahovat následující rozhraní (Interfaces):

1. **Interface 0 (Audio Control - AC):** Společné ovládací rozhraní definující audio topologii (vstupy, výstupy, Feature Unit pro Volume/Mute).
2. **Interface 1 (Audio Streaming - AS OUT):** *Volitelné (Playback).* Pro poslech audia z PC do sluchátkové sady v kukle.
   * Endpoint: Isochronous OUT, Asynchronous.
   * Endpoint: Isochronous IN (Feedback). Nutný pro sdělení PC, jak rychle má data reálně posílat.

3. **Interface 2 (Audio Streaming - AS IN):** *Záznam (Record).* Pro odesílání demodulovaného audia nebo surových I/Q dat do PC.
   * Endpoint: Isochronous IN, Asynchronous.

4. **Interface 3 (CDC Control) & Interface 4 (CDC Data):** Virtuální sériový port (COM) pro CAT povely (přeladění, PTT, diagnostika).
   * Endpointy: Interrupt IN (Control), Bulk IN, Bulk OUT.

## 3. Strategie Asynchronního Audia (24 000 Hz vs 23 437.5 Hz)

Standardní operační systémy nepodporují naši hardwarově čistou frekvenci $23.4375\text{ kHz}$. Zařízení proto bude do OS deklarovat standardní frekvenci **24 000 Hz**.

**Mechanismus toku dat do PC (Záznam - IN):**

* Při 24 kHz (Full-Speed USB, 1 ms SOF) by PC očekávalo přesně 24 vzorků v každém paketu.
* Náš hardware z `TAC5142` a `SX1255` ale generuje vzorky tempem $23.4375\text{ kHz}$. To znamená $23.4375$ vzorků na 1 ms.
* Díky deklaraci asynchronního endpointu (podle specifikace UAC 1.0) nemusíme posílat přesně 24 vzorků. V obsluze SOF přerušení budeme dynamicky kontrolovat počet nasbíraných vzorků z I2S DMA.
* Většinu 1ms paketů odešleme s **23 vzorky**, a zhruba ve 43.75 % případů odešleme paket s **24 vzorky**.
* **Výsledek:** PC dostane data přesně hardwarovou rychlostí. Asynchronní ovladač v OS si data na své straně plynule pře-vzorkuje (resampluje) na uživatelem požadovaných 24 kHz (či 48 kHz), čímž získáme naprosto plynulý stream bez podtékání bufferů nebo lupanců, a to bez potřeby ASRC v hardwaru.

## 4. Architektura firmwaru v C (Software Stack)

Generátor ST USB_DEVICE v CubeMX neumí kompozitní zařízení sestavit automaticky. Přistoupíme k tomu následovně:

* Využijeme knihovnu **STM32 USB Device Library** jako základní "Core" vrstvu.
* Vytvoříme vlastní soubor třídy (např. `usbd_composite.c`), který ručně sestaví kompozitní Configuration Descriptor obsahující jak sekci pro `usbd_audio`, tak pro `usbd_cdc`.
* Obsluha endpointů v `usbd_composite.c` bude rozhazovat příchozí USB přerušení (Data IN/OUT, Setup Request) mezi příslušné handlery Audio a CDC tříd podle čísla endpointu a rozhraní.
* Pro I/Q data můžeme dynamicky využít 32bitový stereo formát (I složka vlevo, Q složka vpravo), který se vejde do šířky pásma Full-Speed USB (cca 1.5 Mbit/s je hluboko pod teoretickým limitem 12 Mbit/s).

# STM32H7 GPIO specifikace

| Název signálu | Pin MCU | Typ I/O | Popis a logika použití |
|---|---|---|---|
| **RADIO_RESET** | `PC0` | Vstup / Výstup | **Hardwarový reset pro SX1255.**<br><br>Využívá se softwarová simulace Open-Drain:<br><br>1. Přepnout pin na `Output Push-Pull` a zapsat **log. 1**.<br><br>2. Čekat **100 μs**.<br><br>3. Přepnout pin zpět na `Input Floating` (High-Z). Tím se sběrnice uvolní a interní pull-down v SX1255 stáhne signál k zemi.<br><br>4. Čekat **5 ms** před zahájením SPI komunikace. |
| **PA_BIAS_ON**  | `PC1` | Výstup (PP) | **Řízení předpětí a aktivace RF koncového stupně.**<br><br>• **Log. 0:** Příjem (RX) – PA je zakázán.<br><br>• **Log. 1:** Vysílání (TX) – Cesta je přepnuta a PA je aktivní.<br><br>*(Poznámka pro HW: Doporučuje se osadit na DPS externí pull-down rezistor např. 100 kΩ, aby byl PA bezpečně vypnutý během bootování MCU, kdy jsou piny ve stavu High-Z).* |
| **RX_BAND** | `PC4` | Výstup (PP) | **Přepínání přijímacích pásmových propustí (BPF).**<br><br>• **Log. 0:** Aktivní filtr pro sdílené kmitočty a PMR (442 MHz – 450 MHz).<br><br>• **Log. 1:** Aktivní filtr pro radioamatérské pásmo (70 cm). |
| **FILTER_TUNE** | `PC5` | Výstup (PP) | **Diagnostický a ladicí režim.**<br><br>Softwarově odpojí běžnou TX/RX cestu od výstupní dolní propusti a připojí vstup na dedikovaný měřicí MMCX konektor. Slouží ke kalibraci a měření přenosu in-circuit. |
| **PTT_TO_MCU**  | `PA2` | Vstup | **Vstup pro vnější klíčování (Push-To-Talk).**<br><br>• **Log. 0:** Vysílání (TX).<br><br>• **Log. 1:** Příjem (RX).<br><br>*(Poznámka pro SW: Pro spolehlivou funkci je nutné v konfiguraci pinu aktivovat interní Pull-Up rezistor a ve firmwaru implementovat debouncing).* |
| **PTT_LED** | `PA3` | Výstup (PP) | **Indikační LED dioda vysílání.**<br><br>• **Log. 0:** Vypnuto.<br><br>• **Log. 1:** Svítí červeně (indikace aktivní TX relace). |
| **SPI_NCS** | *N/A* | Výstup (PP) | **Softwarový Chip Select (NSS) pro SPI3.**<br><br>Slouží ke komunikaci s SX1255. V klidu je výstup držen v **log. 1**. Ovládán ručně kolem blokových (BURST) SPI operací. |
| **I2S_CKIN** | `PC9` | AF Vstup | **Vstup hlavní hodinové synchronizace.**<br><br>Přivádí čistých 36 MHz z palubního TCXO přímo do I2S periferií. Bypassuje interní PLL MCU, čímž zajišťuje absolutní fázovou čistotu bez jitteru pro Zero-IF a audio. |
| **USB_VBUS** | `PA9` | Vstup | **Detekce napětí 5 V z USB (VBUS Sensing).**<br><br>Kritické pro USB specifikaci, protože celé zařízení je "Self-Powered". MCU přes tento pin zjistí fyzické připojení USB kabelu k PC.<br><br>*(Poznámka pro HW: Musí být realizováno přes odporový dělič z 5 V na 3.3 V).* |
| **USB_D- / D+** | `PA11 / PA12` | AF I/O | **Datové linky Full-Speed USB (OTG_HS).**<br><br>Integrovaný fyzický PHY. Připojeno přes ESD ochranu přímo na konektor. Slouží pro USB Audio (UAC) a sériový port (CDC). |

# Dynamické řízení výstupního napětí měniče TLV61047 (U3)

Výstupní napětí zvyšujícího DC/DC měniče TLV61047 (U3) je dynamicky řízeno mikrokontrolérem STM32H725 pomocí metody vstřikování náboje (charge injection) do uzlu zpětné vazby (pin FB). Zdrojem řídicího signálu je hardwarový časovač **TIM3**, jehož výstup PWM je přímo mapován na pin **PC6**.

**Princip činnosti a zpracování signálu:**

1. **Generování a filtrace:** Časovač TIM3 generuje PWM signál o nosné frekvenci $25\text{ kHz}$. Tento signál je veden přes oddělovací rezistor $R_{31}$ do integračního kondenzátoru $C_{30}$. Vzniklá dolní propust (s mezním kmitočtem cca $35\text{ Hz}$) vyhlazuje obdélníkový průběh na čisté stejnosměrné řídicí napětí $V_{CTRL}$, jehož velikost je úměrná střídě (Duty Cycle) PWM.
2. **Izolace smyčky:** Vyhlazené napětí $V_{CTRL}$ je přes izolační rezistor $R_{32}$ přivedeno do zpětnovazebního uzlu měniče. Fyzické oddělení kapacity $C_{30}$ rezistorem $R_{32}$ je naprosto kritické pro zachování fázové rezervy (Phase Margin) a frekvenční stability interního chybového zesilovače TLV61047.
3. **Rovnováha uzlu FB:** V ustáleném stavu udržuje vnitřní regulační smyčka měniče na pinu FB pevné referenční napětí $V_{REF} = 1.233\text{ V}$. Výsledné výstupní napětí $V_{OUT}$ je definováno 1. Kirchhoffovým zákonem pro uzel FB:

$$\frac{V_{OUT} - V_{REF}}{R_{30}} + \frac{V_{CTRL} - V_{REF}}{R_{31} + R_{32}} = \frac{V_{REF}}{R_{33}}$$

**Regulační charakteristika:**
Z výše uvedené rovnice vyplývá, že vztah mezi řídicí střídou PWM a výstupním napětím $V_{OUT}$ je **lineární a nepřímý úměrný**.

* **Při střídě 0 %** ($V_{CTRL} = 0\text{ V}$) odebírá řídicí větev proud z uzlu FB. Chybový zesilovač to kompenzuje zvýšením výstupního napětí na maximální konstrukční hodnotu (cca 28.2 V).
* **Při střídě 100 %** ($V_{CTRL} = 3.3\text{ V}$) je proud naopak vstřikován do uzlu FB, což nutí regulační smyčku snížit výstupní napětí na minimální hodnotu (cca 20.4 V).

Rozlišení časovače TIM3 (čítání do hodnoty 2700) rozděluje tento rozsah na jemné kroky, kde změna střídy o 1 bit (LSB) odpovídá změně výstupního napětí o přibližně 3 mV. Tento mechanismus poskytuje rádiové části vysoce precizní a lineární řízení napájecího napětí koncového stupně, které lze jednoduše ovládat přímým zápisem do registru střídy v mikrokontroléru.

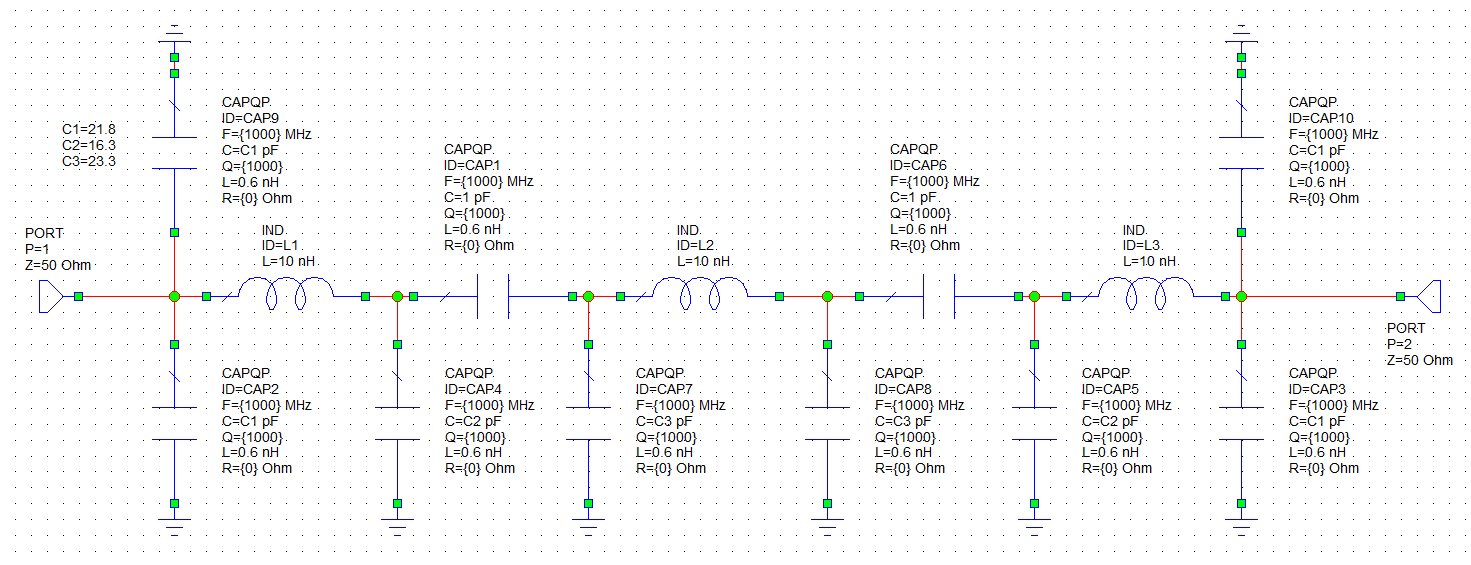
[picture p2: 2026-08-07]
Doc/Filter70cm.png

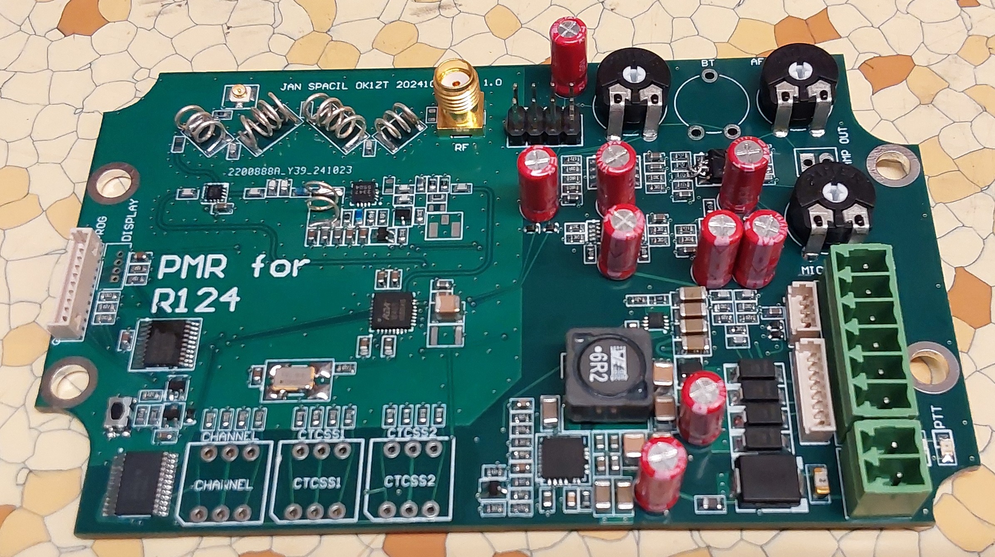
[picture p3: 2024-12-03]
Doc/Pic/2024-12-03 16.33.33.jpg

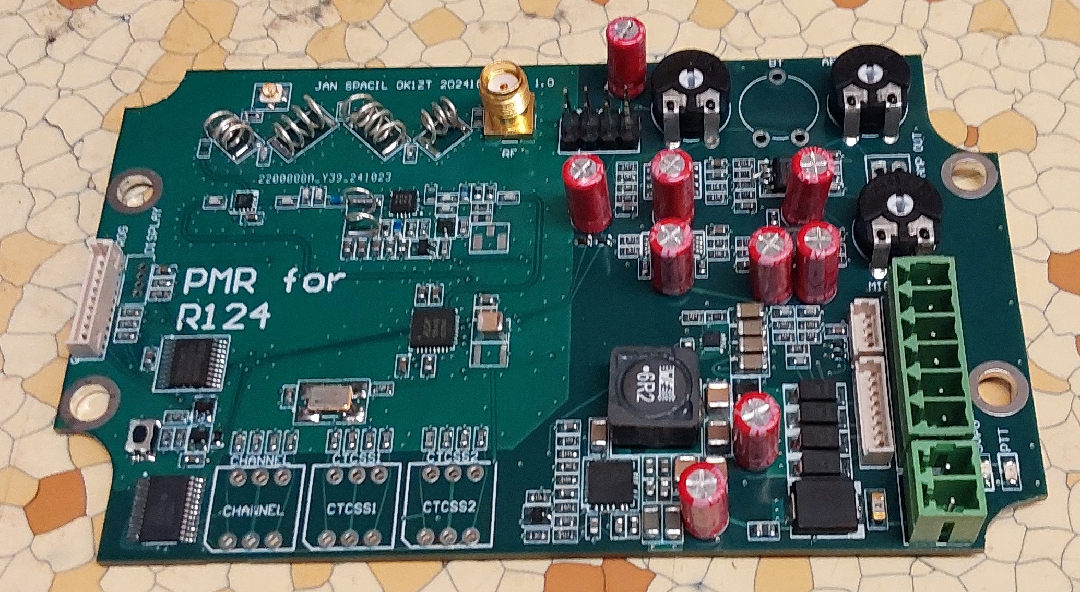
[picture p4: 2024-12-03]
Doc/Pic/2024-12-03 16.33.28.jpg

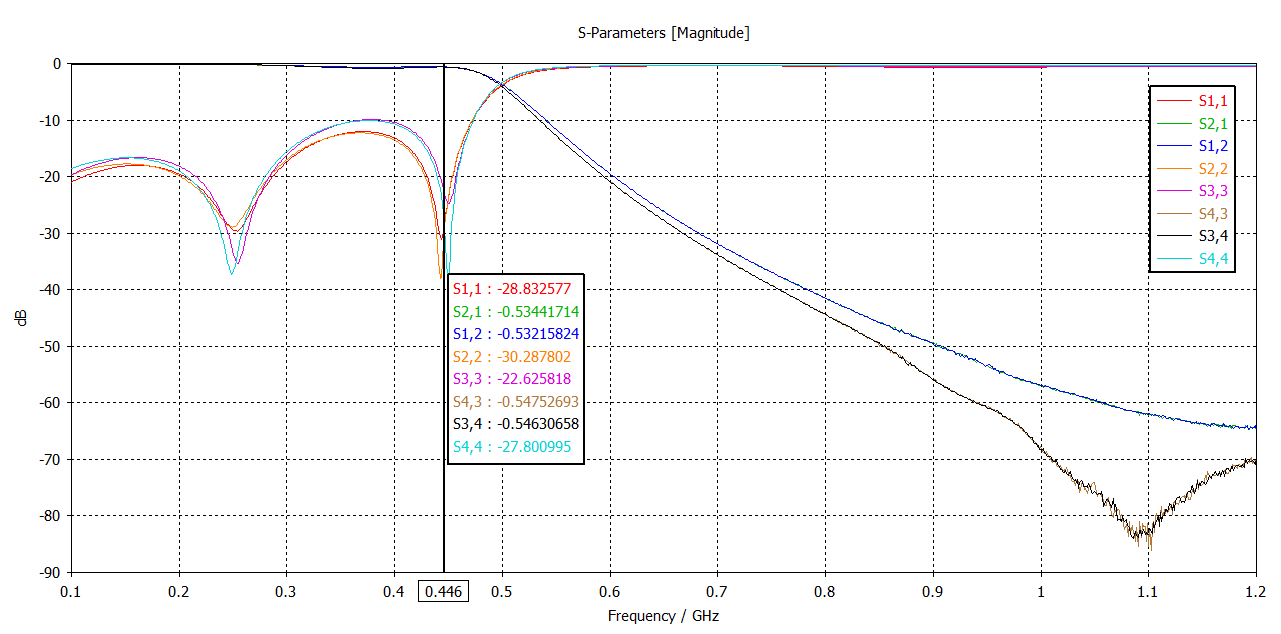
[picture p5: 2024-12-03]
Doc/Pic/S-Parameters-of-filter.png

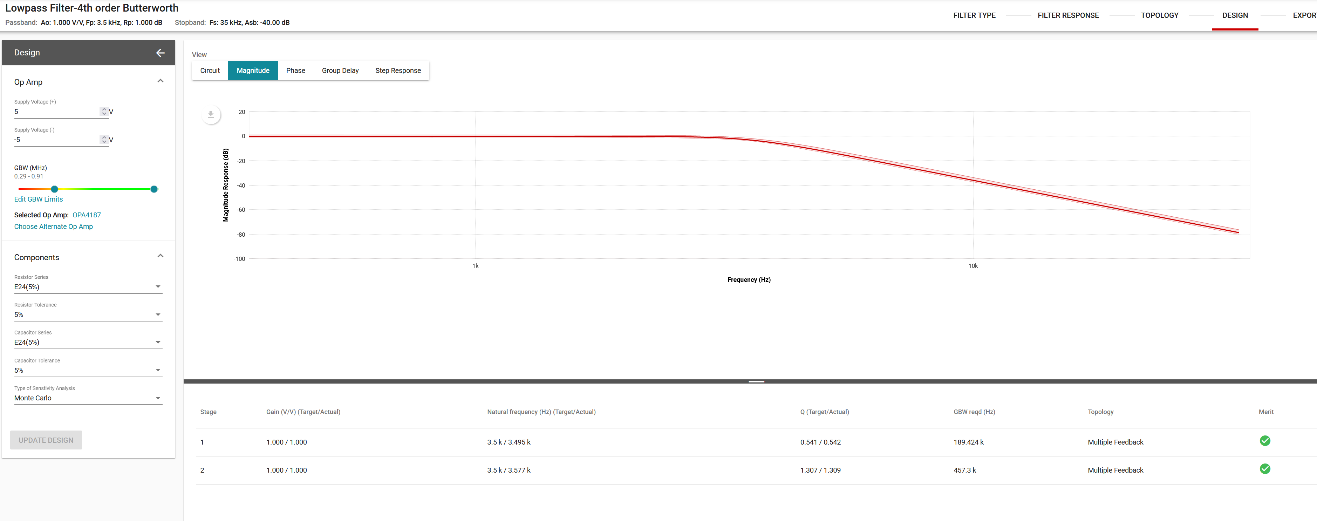
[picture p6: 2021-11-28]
Altium/Qadrature FM demodulator/Prenos filtru.PNG

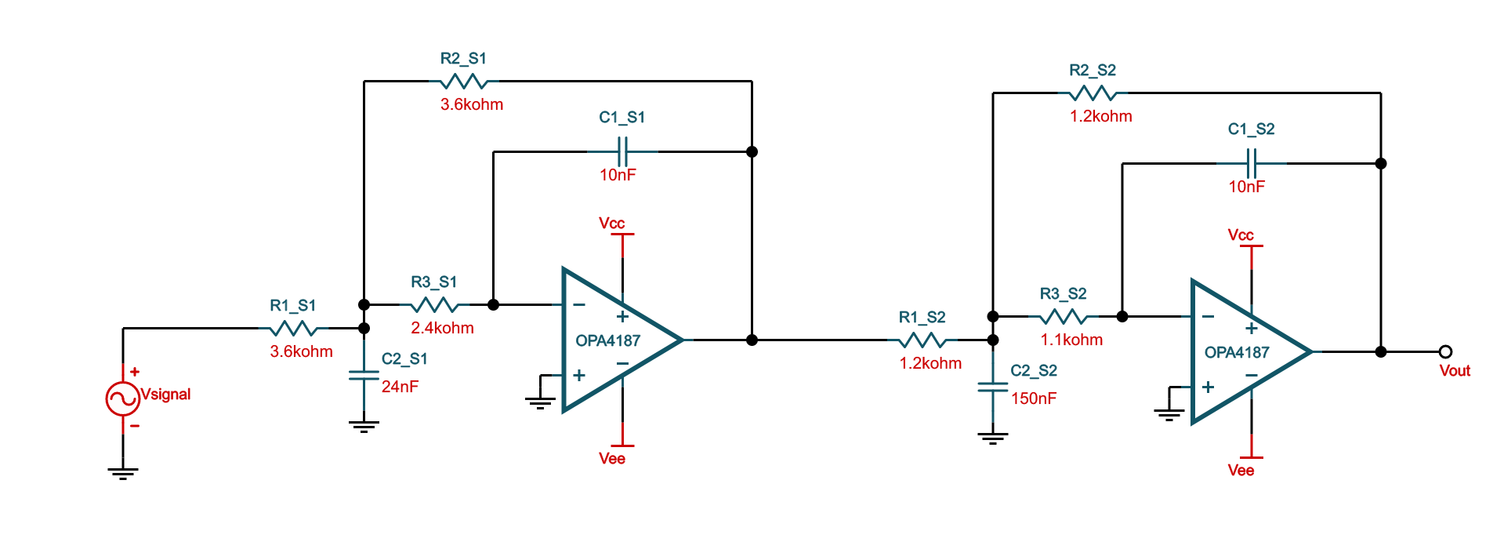
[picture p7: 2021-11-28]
Altium/Qadrature FM demodulator/Zapojnei filtru.PNG

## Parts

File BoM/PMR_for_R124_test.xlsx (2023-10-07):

Comment | Description | Designator | Footprint | LibRef | Qty radio | Qty testy | Qty rspi power | Qty celkem | Supplier 1 | Supplier Part Number 1 | Supplier 2 | Supplier Part Number 2 | Supplier 3 | Supplier Part Number 3 | Supplier 4 | Supplier Part Number 4
10uF, ALU 63V | WURTH ELEKTRONIK - 860080772001 - CAP, ALU ELEC, 10UF, 63V, RADIAL | C1, C3, C9, C15, C16, C20 | WCAP-ATLI_5x11x2 | 860080772001 | 6 | 3 | 1 | 19 | Mouser | 710-860080772001 | Farnell | 2465955 | Digi-Key | 732-9121-1-ND
10n, 50V, C0G | Multilayer Ceramic Capacitors MLCC - SMD/SMT 0603 50VDC 10000pF 5% C0G | C2, C4, C6, C8, C41 | SMD0603 | GRM1885C1H103JA01D | 5 | 4 |  | 14 | Mouser | 81-GRM1885C1H103JA1D | Farnell | 2456107
1u, 50V, X7R | 0603 1 uF 50 V ±10% Tolerance X7R SMT Multilayer Ceramic Capacitor | C21, C22, C29, C30, C32, C33 | SMD0603 | UMK107AB7105KA-T | 18 |  |  | 36 | Mouser | 963-UMK107AB7105KA-T | Farnell | 2779113 | Digi-Key | 587-3247-6-ND
47u, 10V, X7R | Cap Ceramic 47uF 10V X7R 20% Pad SMD 1210 125C T/R | C23, C24, C25, C26 | SMD1210 | CL32B476MPJNNNE | 4 |  | 4 | 24 | Mouser | 187-CL32B476MPJNNNE | Arrow Electronics | CL32B476MPJNNNE
10u, 50V, X5R | CAP CER 10UF 50V X5R 1206 | C27, C28, C34, C37, C38, C39, C40 | SMD1206 | UMK316BBJ106KL-T | 7 | 2 | 2 | 24 | Mouser | 963-UMK316BBJ106KL-T | Digi-Key | 587-5960-1-ND | Avnet | UMK316BBJ106KL-T
100u, alu, 25V | CAP 100 UF 20% 25 V | C31 | WCAP-ATLI_6.3x11x2.5 | 860010473007 | 1 |  | 1 | 6 | Mouser | 710-860010473007 | Farnell | 2465675 | Digi-Key | 732-8630-1-ND
6p8, 50V, C0G | WURTH ELEKTRONIK - 885012006050 - CAP, 6.8PF, 50V, C0G/NP0, 0603 | C42, C44 | SMD0603 | 885012006050 | 2 |  |  | 4 | Mouser | 710-885012006050 | Farnell | 2533851 | Digi-Key | 732-7792-1-ND
12p 100V C0G 1% | Cap Ceramic 12pF 100V C0G 1% SMD 0603 125°C T/R | C43 | SMD0603 | 06031U120FAT2A | 1 |  |  | 2 | Mouser | 581-06031U120FAT2A
BAS16 | ON SEMICONDUCTOR/FAIRCHILD - BAS16 - DIODE, SWITCHING, 0.2A 85V, SOT-23 | D1, D2 | SOT23 (TO-236AB) | BAS16 | 2 |  |  | 4 | Mouser | 621-MMBD914-7-F
RED | MULTICOMP - MCL-S270SRC - LED, SMD, 0805, SUPER-RED | D3 | MCL-S270 | MCL-S270SRC | 1 | 1 |  | 3 | Farnell | 1581239 | Newark | 14N9358
GREEN | MULTICOMP - MCL-S270GC - LED, 0805, GREEN, 10MCD, 570NM | D5, D8, D9 | MCL-S270 | MCL-S270GC | 3 | 3 | 1 | 13 | Farnell | 1581242 | Newark | 14N9356
CG0603MLC-24LEA | ESD Suppressor ±25KV 2-Pin Case 0603 T/R | D6 | SMD0603 - R | CG0603MLC-24LEA | 1 |  |  | 2 | Mouser | 652-CG0603MLC-24LEA | Digi-Key | CG0603MLC-24LEA-ND | Arrow Electronics | CG0603MLC-24LEA
HDSP-521E | Displays Segmented Panel 2DIGIT 16LED Hi-Eff. Red CA 18-Pin DIP Tube | D7 | HDSP-521E | HDSP-521E | 1 | 1 |  | 3 | Mouser | 630-HDSP-521E | Farnell | 1003314 | Digi-Key | 516-1206-5-ND | RSComponents | 8305126
SMDJ48A | J Series 53.3 V 3000 W Surface Mount Uni-Directional TVS Diode - DO-214AB | D10 | DO-214AB | SMDJ48A | 1 |  |  | 2 | Mouser | 576-SMDJ48A | Farnell | 2762843 | Digi-Key | SMDJ48ACT-ND
SMA6J5.0CA | ESD Suppressors / TVS Diodes 600W 5V 5% Bi-Directional | D11, D12, D13, D14 | DO-214AC | SMA6J5.0CA | 4 |  |  | 8 | Mouser | 576-SMA6J5.0CA | Farnell | 3010381 | Digi-Key | 18-SMA6J5.0CACT-ND
0458002.DR | FUSE BRD MNT 2A 48VAC 75VDC 1206 | F1 | SMD1206 - FUSE | 0458002.DR | 1 |  |  | 2 | Mouser | 576-0458002.DR | Farnell | 1702533 | Digi-Key | F2931CT-ND
MCX 73415-1691 | MOLEX - 73415-1691 - RF COAXIAL, MCX, STRAIGHT JACK, 50OHM | J1, J2 | MCX_SMD_vertical | 73415-1691 | 2 |  |  | 4 | Mouser | 538-73415-1691 | Farnell | 1909246 | Digi-Key | WM5559-ND | Digi-Key | WM5541-ND
53047-1010 | 1.25mm Pitch, PicoBlade PCB Header, Single Row, Vertical, Through Hole, Tin Plating, Friction Lock, 10 Circuits, Tray, 2.30mm PC Tail Length | J3 | 530471010 | 53047-1010 | 1 |  | 1 | 6 | Mouser | 538-53047-1010 | Arrow | 53047-1010 | Digi-Key | WM1739-ND | Farnell | 9733086
53047-0410 | 1.25mm Pitch, PicoBlade PCB Header, Single Row, Vertical, Through Hole, Tin Plating, Friction Lock, 4 Circuits, Tray, 2.30mm PC Tail Length | J4 | 530470410 | 53047-0410 | 1 | 2 |  | 4 | Mouser | 538-53047-0410 | Farnell | 9733060 | Digi-Key | WM1733-ND | Avnet | 0530470410
61300211121 | CONN HEADER 2 POS 2.54 | J7 | Header 2 2.54mm | 61300211121 | 1 |  |  | 2 | Mouser | 710-61300211121 | Farnell | 2356153 | Digi-Key | 732-5315-ND
7447798620 | Power Inductors - SMD WE-PDF 1064 6.2uH 9.4A 9.5mohm | L1 | WE-PDF_1064 | CMP-0227-00046-2 | 1 |  | 1 | 6 | Mouser | 710-7447798620
24n | RF inductor, tunable, aluminum core, RoHS | L2, L3 | Uni5 | 164-03A06L | 2 |  |  | 4 | Mouser | 994-164-03A06L
NX3008NBKW | NXP - NX3008NBKW - MOSFET, N CH, 30V, 350MA, SOT323 | Q1, Q2, Q3, Q4 | SOT323 | NX3008NBKW | 4 |  | 1 | 12 | Mouser | 771-NX3008NBKW,115 | Farnell | 2069546 | Arrow | NX3008NBKW,115
47k, 0.1% | RES SMD 47K OHM 0.1% 1/10W 0603 | R4, R5, R6, R10, R12, R13 | SMD0603 - R | RT0603BRD0747KL | 6 | 6 |  | 18 | Mouser | 603-RT0603BRD0747KL | Digi-Key | YAG1667CT-ND | Arrow Electronics | RT0603BRD0747KL
4k7, 0.1% | Res Thin Film 0603 4.7K Ohm 0.1% 0.1W(1/10W) ±10ppm/C Molded SMD Paper T/R | R8 | SMD0603 - R | RT0603BRB074K7L | 1 | 1 |  | 3 | Mouser | 603-RT0603BRB074K7L | Digi-Key | YAG4447CT-ND
KMR241G | C & K COMPONENTS - KMR241G LFS - SWITCH, SMD, 4N, 0.05A, 32VDC, SPST-NO | SW1, SW2, SW3 | KMR2 | KMR241G LFS | 3 | 3 |  | 9 | Mouser | 611-KMR241GLFS | Farnell | 1437637 | Digi-Key | CKN10248DKR-ND
NE5532DR | 2-channel, 10-MHz, 26-V output swing, low-noise audio op amp 8-SOIC 0 to 70 | U1, U2 | SOIC08 | NE5532DR | 2 | 2 |  | 6 | Mouser | 595-NE5532DR | Farnell | 3117312 | Digi-Key | 296-13622-6-ND
AD8532ARUZ | Low Cost, 250 mA Output, Single-Supply Amplifiers, DUAL, CMOS, TSSOP, 8PIN, PLASTIC | U3 | TSSOP08 | AD8532ARUZ-REEL | 1 |  |  | 2 | Mouser | 584-AD8532ARUZ-R | Farnell | 4019791RL | Digi-Key | 505-AD8532ARUZ-REELCT-ND
SA818S-U | 1W Embedded small size walkie talkie module | U4 | SA818S | SA818S-U | 1 |  |  | 2
SIC479ED-T1-GE3 | Switching Voltage Regulators microBUCK 4.5-55V; 3A | U5 | POWERPAK_MLP55-27L_VIS | SIC479ED-T1-GE3 | 1 |  | 1 | 6 | Mouser | 78-SIC479ED-T1-GE3 | Digi-Key | 742-SIC479ED-T1-GE3CT-ND | Newark | 23AH3586 | Farnell | 3212621
TPS7A4101DGNR | Single Output LDO, 50 mA, Adjustable 1.175 to 48 V Output, 7 to 50 V Input, 8-pin MSOP (DGN), -40 to 125 degC, Green (RoHS & no Sb/Br) | U6 | DGN0008B_M | CMP-0394-01264-2 | 1 |  |  | 2 | Mouser | 595-TPS7A4101DGNR
LDK320M33R | IC REG LINEAR 200MA SOT23-5 | U7 | SOT23-5 | LDK320M33R | 1 | 2 |  | 4 | Mouser | 511-LDK320M33R | Farnell | 3130011 | Digi-Key | 497-17034-1-ND
TCA9539PWR | Remote 16-Bit I2C and SMBus, Low-Power I/O Expander with Interrupt Output, Reset & Config. Register, 1.65 to 5.5 V, -40 to 85 degC, 24-pin TSSOP (PW), Green (RoHS & no Sb/Br) | U8 | PW0024A_M | CMP-0314-00251-2 | 1 | 2 |  | 4 | Mouser | 595-TCA9539PWR
STM32G030F6P6TR | MCU 32-Bit STM32 ARM Cortex-M0+ RISC 32KB Flash 2V to 3.6V 20-Pin TSSOP T/R | U9 | TSSOP20 | STM32G030F6P6TR | 1 |  |  | 2 | Mouser | 511-STM32G030F6P6TR | Digi-Key | 497-STM32G030F6P6TRCT-ND
TCA9534APWR | IC I/O EXPANDER I2C 8B 16TSSOP |  | TSSOP16N |  |  | 1 |  | 1 | Mouser | 595-TCA9534APWR
ADE1004 | Switch DIP OFF ON SPST 10 Extended Slide 0.1A 24VDC PC Pins 2.54mm Thru-Hole Tube |  |  |  |  | 1 |  | 1 | Mouser | 506-ADE1004
53047-0810 | 1.25mm Pitch, PicoBlade PCB Header, Single Row, Vertical, Through Hole, Tin Plating, Friction Lock, 8 Circuits, Tray, 2.30mm PC Tail Length |  |  |  |  | 2 |  | 2 | Mouser | 538-53047-0810
15134-1002 | Rectangular Cable Assemblies PicoBlade CBL ASSY 10CKT 150MM NTL |  |  |  |  | 3 |  | 3 | Mouser | 538-15134-1002
 | Rectangular Cable Assemblies 8 Circuit 50MM Picoblade |  |  |  |  | 2 |  | 2 | Mouser | 538-15134-0800
 | Rectangular Cable Assemblies 8 Circuit 100MM Picoblade |  |  |  |  | 2 |  | 2 | Mouser | 538-15134-0801
 | Rectangular Cable Assemblies 8 CIRCUIT PICOBLADE R:BLUNT CABLE 75MM |  |  |  |  | 2 |  | 2 | Mouser | 538-218112-0800
 | Circular Metric Connectors M12 PANEL PCB CONN 8PIN M CONN M PIN |  |  |  |  | 2 |  | 2 | Mouser | 523-M12A08PMMPSF8001
 | Sensor Cables / Actuator Cables M12 OVERMOLD CABLE HIGHLY FLEX L-1M |  |  |  |  | 2 |  | 2 | Mouser | 523-M12A08BFFMSL8N01
 | RF Adapters - Between Series SMA JACK TO N BLKHD JACK ADAPTER |  |  |  |  | 1 |  | 1 | Mouser | 523-242125
 | RF Cable Assemblies 5 inch SMA M/M IL1.04dB/ft @ 16GHz |  |  |  |  | 1 |  | 1 | Mouser | 549-CCSMA-MM-086-5
1u, 50V, X5R | Multilayer Ceramic Capacitor 1uF 50V 20% 0402 Paper T/R | C1, C2, C4, C5, C12, C13, C14, C18 | SMD0402 - Velky | UMK105CBJ105MV-F |  |  | 8 | 32 | Mouser | 963-UMK105CBJ105MV-F | Farnell | 3216460 | Digi-Key | 587-6278-1-ND | RSComponents | 1034095
10u, 10V, X6S | Cap Ceramic 10uF 10V X6S 20% Pad SMD 0603 105C Automotive T/R | C15 | SMD0603 | GRT188C81A106ME13D |  |  | 1 | 4 | Mouser | 81-GRT188C81A106ME3D | Farnell | 3582904 | Digi-Key | 490-12283-6-ND
SMDJ33A | SMDJ Series 3000 W 33 V Surface Mount Uni-Directional TVS Diode - DO-214AB | D1 | DO-214AB | SMDJ33A |  |  | 1 | 4 | Mouser | 576-SMDJ33A | Farnell | 1827630 | RSComponents | 7645717P
SMDJ5.0A-T7 | TVS DIODE 5V 9.2V DO214AB | D2 | DO-214AB | SMDJ5.0A-T7 |  |  | 1 | 4 | Mouser | 576-SMDJ5.0A-T7 | Digi-Key | 18-SMDJ5.0A-T7CT-ND | Arrow Electronics | SMDJ5.0A-T7
Raspberry PI 3 GPIO Header F |  | H1 |  |  |  |  | 1 | 2 | Mouser | 855-M20-6102045
61300421121 | CONN HEADER DUAL 4 POS 2.54 | J7 | 61300421121 | 61300421121 |  |  | 1 | 4 | Mouser | 710-61300421121 | Farnell | 2356130 | Digi-Key | 732-5294-ND
1R, 1% | SMD Chip Resistor, 1 Ohm, ± 1%, 100 mW, 0603 [1608 Metric], Thick Film, General Purpose | R7 | SMD0603 - R | RC0603FR-071RL |  |  | 1 | 4 | Mouser | 603-RC0603FR-071RL | Newark | 75X0138 | Digi-Key | 311-1.00HRCT-ND
Header pro raspi |  |  |  |  |  |  |  | 4 | Mouser | 710-61304021821

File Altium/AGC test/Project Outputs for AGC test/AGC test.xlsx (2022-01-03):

Comment | Designator | Footprint | LibRef | Quantity
1k8, 1% | R4, R5, R6, R7, R10, R11, R12 | SMD0603 - R | RC0603FR-071K8L | 7
1u, 25V, X7R | C1, C5, C15, C16, C17, C18, C19 | SMD0603 | CGA3E1X7R1E105K080AC | 7
10k, 1% | R14, R15, R18, R19, R20 | SMD0603 - R | RC0603FR-0710KL | 5
10n, 50V, C0G | C6, C7, C8, C11 | SMD0603 | GRM1885C1H103JA01D | 4
1M, 1% | R23, R24, R25 | SMD1206 - R | ERJ-8ENF1004V | 3
4k7, 1% | R17, R22, R26 | SMD0603 - R | AC0603FR-074K7L | 3
51R, 1% | R1, R8, R9 | SMD0603 - R | CRCW060351R0FKEA | 3
MCX 73366-0061 | J10, J11, J12 | 73366-0061 | 73366-0061 | 3
22p, 50V, C0G | C9, C10 | SMD0603 | MC0603N220J500CT | 2
100u, alu, 25V | C13, C14 | WCAP-ATLI_6.3x11x2.5 | 860010473007 | 2
20k, 1% | R21 | SMD0603 - R | AC0603FR-0720KL | 1
30k, 1% | R16 | SMD0603 - R | RC0603FR-0730KL | 1
100n, 25V, X7R | C12 | SMD0603 | 06033C104KAT2A | 1
200R, 1% | R13 | SMD0603 - R | RC0603FR-13200RL | 1
61300211121 | J9 | Header 2 2.54mm | 61300211121 | 1
61300311121 | J13 | Header 3 2.54mm | 61300311121 | 1
691322110003 | J14 | 691322110003 | 691322110003 | 1
BAT42WS-E3-08 | D1 | SOD-323 | BAT42WS-E3-08 | 1
F-10M7-K6 | U4 | F-10M7-K6 | F-10M7-K6 | 1
LM324PWR | U6 | TSSOP14 | LM324PWR | 1
TL026CD | U5 | SOIC08 | TL026CD | 1
TLV3501AIDR | U3 | SOIC08 | TLV3501AIDR | 1

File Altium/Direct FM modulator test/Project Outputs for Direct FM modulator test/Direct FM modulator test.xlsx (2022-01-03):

Comment | Designator | Footprint | LibRef | Quantity
1u, 6.3V, X6S | C4, C7, C8, C9, C10, C12, C13, C14 | SMD0402 | GRT155C80J105KE01D | 8
100R, 1% | R2, R6, R7, R8, R9, R10, R11 | SMD0402 - R | RC0402FR-07100RL | 7
10u, 10V, X6S | C16, C17, C20, C22 | SMD0603 | GRT188C81A106ME13D | 4
1n, 50V, X7R | C2, C5 | SMD0402 | MC0402B102K500CT | 2
49R9, 0.1% | R1, R3 | SMD0402 - R | AT0402BRD0749R9L | 2
120 ohm | F1, F2 | SMD0805 - R | 742792023 | 2
470p, 50V, C0G | C1, C3 | SMD0402 | GCM1555C1H471FA16D | 2
CDDFN2-T5.0LC | D1, D2 | CDDFN2-T5.0LC | CDDFN2-T5.0LC | 2
MCX 73366-0061 | J1, J2 | 73366-0061 | 73366-0061 | 2
PAT1220-C-2DB-T5 | U3, U4 | PAT1220 | PAT1220-C-2DB-T5 | 2
3n3, 50V, X7R | C11 | SMD0603 | 0603B332K500CT | 1
10k, 1% | R5 | SMD0603 - R | RC0603FR-0710KL | 1
10n, 50V, X7R | C15 | SMD0402 | MC0402B103K500CT | 1
18n, 35V, C0G | C6 | SMD0603 | C1608C0G1V183J080AC | 1
100n, 16V, X7R | C19 | SMD0402 | MC0402B104K160CT | 1
270R, 1% | R4 | SMD0603 - R | WR06X2700FTL | 1
470n, 50V, X7R | C18 | SMD0603 | C1608X7R1H474K080AC | 1
470uF, ALU 25V | C21 | WCAP-ATG8_8x11.5x3.5 | 860010474013 | 1
AFS446.0W02-TD01 | U2 | AFS446.0W02-TD01 | AFS446.0W02-TD01 | 1
LMX2572LPRHAT | U1 | VQFN50P600X600X100_HS-41N | LMX2572LPRHAT | 1
MABA-007159-000000 | T1 | MABA-007159-000000 | MABA-007159-000000 | 1
PMOD M | J3 | PMOD M | PMOD M | 1
SG-8018CG 25.0000M-TJHPA3 | XO1 | XO 2.5x2.0mm | SG-8018CG 25.0000M-TJHPA3 | 1

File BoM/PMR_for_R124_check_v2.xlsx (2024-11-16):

Comment | Description | Designator | Footprint | Quantity | Supplier Part Number 1
1u, 25V, X7R | CAP CER 1UF 25V X7R 0603 | C1, C2, C3, C34, C35, C36, C37, C41, C45, C46, C47, C48, C54, C55, C56, C57, C58, C59, C60, C61, C62, C63, C69, C70, C71 | SMD0603 | 25 | 810-CGA3E1X7R1E105K
10uF, ALU 63V | WURTH ELEKTRONIK - 860080772001 - CAP, ALU ELEC, 10UF, 63V, RADIAL | C4, C15, C27, C30, C33, C42, C43, C44, C51 | WCAP-ATLI_5x11x2 | 9 | 710-860080772001
1u, 50V, X7R | 0603 1 uF 50 V ±10% Tolerance X7R SMT Multilayer Ceramic Capacitor | C5, C6, C13, C14, C16, C17, C25 | SMD0603 | 7 | 963-UMK107AB7105KA-T
47u, 10V, X7R | Cap Ceramic 47uF 10V X7R 20% Pad SMD 1210 125C T/R | C7, C8, C9, C10, C53 | SMD1210 | 5 | 187-CL32B476MPJNNNE
10u, 50V, X5R | CAP CER 10UF 50V X5R 1206 | C11, C12, C18, C21, C22, C23, C24, C26 | SMD1206 | 8 | 963-UMK316BBJ106KL-T
100n, 25V, X7R | AVX - 06033C104KAT2A - CAP, MLCC, X7R, 0.1UF, 25V, 0603 | C19 | SMD0603 | 1 | 2530141
33n, 50V, X7R | 0603 33nF Ceramic Multilayer Capacitor; 50 V dc; +125degC; X7R Dielectric; +/-5% | C20 | SMD0603 | 1 | 581-06035C333J
10n, 50V, C0G | Multilayer Ceramic Capacitors MLCC - SMD/SMT 0603 50VDC 10000pF 5% C0G | C28, C29, C31, C32 | SMD0603 | 4 | 81-GRM1885C1H103JA1D
9p1 ±0.1p 200V C0G | Cap SMD U" Series Low ESR 0603 200V C0G (NP0) 9.1pF ±0.1pF for Comm/RF/µWave Apps Ni/Sn Plated 7"T/R" | C38, C40 | SMD0603 | 2 | 581-06032U9R1BAT2A
10p 200V 1% C0G | Cap Ceramic 10pF 200V C0G 1% Pad SMD 0603 125°C Ultra Low ESR T/R | C39, C64, C65 | SMD0603 | 3 | 581-06032U100FAT2A
100p, 250V, C0G | CAP CER 100PF 250V C0G/NP0 0603 | C49, C50, C66 | SMD0603 | 3 | 732-12167-1-ND
47p, 50V, C0G | CAP CER 47PF 50V C0G/NP0 0603 | C67 | SMD0603 | 1 | 80-C0603C470J5G
12p 100V C0G 1% | Cap Ceramic 12pF 100V C0G 1% SMD 0603 125°C T/R | C68 | SMD0603 | 1 | 581-06031U120FAT2A
SMDJ48A | J Series 53.3 V 3000 W Surface Mount Uni-Directional TVS Diode - DO-214AB | D1 | DO-214AB | 1 | 576-SMDJ48A
SMA6J5.0CA | ESD Suppressors / TVS Diodes 600W 5V 5% Bi-Directional | D2, D3, D4, D5 | DO-214AC | 4 | 576-SMA6J5.0CA
PESD3V3S1UB | TVS DIODE 3.3V 20V SOD523 | D6, D7, D9, D12, D13 | SOD523 | 5 | 771-PESD3V3S1UB-T/R
RED | MULTICOMP - MCL-S270SRC - LED, SMD, 0805, SUPER-RED | D8 | MCL-S270 | 1 | 1581239
GREEN | MULTICOMP - MCL-S270GC - LED, 0805, GREEN, 10MCD, 570NM | D10 | MCL-S270 | 1 | 1581242
CG0603MLC-24LEA | ESD Suppressor ±25KV 2-Pin Case 0603 T/R | D11 | SMD0603 - R | 1 | 652-CG0603MLC-24LEA
0458002.DR | FUSE BRD MNT 2A 48VAC 75VDC 1206 | F1 | SMD1206 - FUSE | 1 | 576-0458002.DR
120 ohm | WURTH ELEKTRONIK - 742792023 - FERRITE BEAD, 0.03OHM, 3A, 0805 | FR1 | SMD0805 - R | 1 | 710-742792023
691321100002 | WR-TBL Series 3211 - 3.50 mm Vertical PCB Header | J1 | 691321100002 | 1 | 710-691321100002
691321100006 | WR-TBL Series 3211 - 3.50 mm Vertical PCB Header | J2 | 691321100006 | 1 | 710-691321100006
53047-0810 | 1.25mm Pitch, PicoBlade PCB Header, Single Row, Vertical, Through Hole, Tin Plating, Friction Lock, 8 Circuits, Tray, 2.30mm PC Tail Length | J3 | 530470810 | 1 | 538-53047-0810
53047-0410 | 1.25mm Pitch, PicoBlade PCB Header, Single Row, Vertical, Through Hole, Tin Plating, Friction Lock, 4 Circuits, Tray, 2.30mm PC Tail Length | J4, J6 | 530470410 | 2 | 538-53047-0410
53047-1010 | 1.25mm Pitch, PicoBlade PCB Header, Single Row, Vertical, Through Hole, Tin Plating, Friction Lock, 10 Circuits, Tray, 2.30mm PC Tail Length | J5 | 530471010 | 1 | 538-53047-1010
61300211121 | CONN HEADER 2 POS 2.54 | J7 | Header 2 2.54mm | 1 | 710-61300211121
MCX 73415-1691 | MOLEX - 73415-1691 - RF COAXIAL, MCX, STRAIGHT JACK, 50OHM | J8 | MCX_SMD_vertical | 1 | 538-73415-1691
UFL | CONN UMC JACK STR SMD | J9, J11 | CONUFL001-SMD-T | 2 | CONUFL001-SMD-TCT-ND
61300821121 | CONN HEADER DUAL 8 POS 2.54 | J10 | 61300821121 | 1 | 710-61300821121
7447798620 |  | L1 | WE-PDF_1064 | 1
22n94nH |  | L2, L5 | Air-Inductor-25nH | 2
38n04nH |  | L3, L4 | Air-Inductor-40nH | 2
22nH |  | L6 | Air-Inductor-25nH | 1
12n, 2%, 4.1GHz | Fixed Inductors 0603HP Hi Perfrmnce 12 nH 2 % 1.1 A | L7 | SMD0603 - L | 1 | 994-0603HP-12NXGLU
4n7, 2%, 7.9GHz | Fixed Inductors 0603HP Hi Perfrmnce 4.7 nH 2 % 1.1 A | L9 | SMD0603 - L | 1 | 994-0603HP-4N7XGLU
6n8, 2%, 5.8GHz | Fixed Inductors RF Chip Inductor 6.8 nH 2 % 1.4 A | L10 | SMD0603 - L | 1 | 994-0603HP-6N8XGLU
NX3008NBKW | NXP - NX3008NBKW - MOSFET, N CH, 30V, 350MA, SOT323 | Q1, Q2, Q4, Q5 | SOT323 | 4 | 771-NX3008NBKW,115
NX3008PBKW | NXP - NX3008PBKW - MOSFET, P CH, 30V, 200MA, SOT323 | Q3 | SOT323 | 1 | 2069551
22R, 1% | YAGEO (PHYCOMP) - RC0603FR-0722RL - RES, THICK FILM, 22R, 1%, 0.1W, 0603 | R1, R4, R21, R37, R54, R60, R67 | SMD0603 - R | 7 | 603-RC0603FR-0722RL
10k, 1% | YAGEO (PHYCOMP) - RC0603FR-0710KL - RES, THICK FILM, 10K, 1%, 0.1W, 0603 | R2, R12, R13, R27, R30, R34, R52, R53, R58, R59, R65, R66 | SMD0603 - R | 12 | 603-RC0603FR-0710KL
470R, 1% | YAGEO RC0603FR-07470RL SMD Chip Resistor, Thick Film, 470 ohm, 50 V, 0603 [1608 Metric], 100 mW, 1%, RC Series | R3, R16 | SMD0603 - R | 2 | 603-RC0603FR-07470RL
100k, 1% | RES SMD 100K OHM 1% 1/10W 0603 | R5, R6, R14, R22, R36, R40, R41, R42, R43, R44, R45, R46, R47, R48, R49, R50, R51, R75, R76 | SMD0603 - R | 19 | 603-RC0603FR-07100KL
3k3, 1% | YAGEO - RC0603FR-073K3L - SMD Chip Resistor, 0603 [1608 Metric], 3.3 kohm, RC Series, 75 V, Thick Film, 100 mW | R7, R8, R72 | SMD0603 - R | 3 | 603-RC0603FR-073K3L
51k, 1% | RES SMD 51K OHM 1% 1/10W 0603 | R9, R10 | SMD0603 - R | 2 | 603-RC0603FR-0751KL
1k3, 1% | RES SMD 1.3K OHM 1% 1/10W 0603 | R11, R17 | SMD0603 - R | 2 | 603-RC0603FR-071K3L
1R, 1% | SMD Chip Resistor, 1 Ohm, ± 1%, 100 mW, 0603 [1608 Metric], Thick Film, General Purpose | R15 | SMD0603 - R | 1 | 603-RC0603FR-071RL
39k, 1% | RES SMD 39K OHM 1% 1/10W 0603 | R18 | SMD0603 - R | 1 | 603-RC0603FR-0739KL
680k, 1% | RES SMD 680K OHM 1% 1/10W 0603 | R19 | SMD0603 - R | 1 | 71-CRCW0603-680K-E3
220k, 1% | RES SMD 220K OHM 1% 1/10W 0603 | R20 | SMD0603 - R | 1 | 603-RC0603FR-07220KL
4k7, 0.1% | Res Thin Film 0603 4.7K Ohm 0.1% 0.1W(1/10W) ±10ppm/C Molded SMD Paper T/R | R23, R28, R29, R31, R33 | SMD0603 - R | 5 | 603-RT0603BRB074K7L
0R | RES SMD 0 OHM JUMPER 1/10W 0603 | R25, R38, R39, R68, R74 | SMD0603 - R | 5 | 71-CRCW0603-0-E3
47k, 0.1% | RES SMD 47K OHM 0.1% 1/10W 0603 | R26, R35 | SMD0603 - R | 2 | 603-RT0603BRD0747KL
10k | Resistor Carbon Film Trimmer Top Adjustment 10K Ohm 20% 3/20W 1 Turn PC Pin Through Hole Bulk | R32, R55, R61, R63 | V10 | 4 | 531-PT10LV113A22PMS
100R, 1% | MULTICOMP - MCWR06X1000FTL - RES, THICK FILM, 100R, 1%, 0.1W, 0603 | R56, R62, R64 | SMD0603 - R | 3 | 2447227
22k, 1% | Res Thick Film 0603 22K Ohm 1% 0.1W(1/10W) ±100ppm/C Molded SMD Paper T/R | R57 | SMD0603 - R | 1 | 603-RC0603FR-1322KL
82R, 1% | WALSIN - WR06X82R0FTL - RESISTOR, THICK FILM, 82R, 1%, 75V, 0603 | R69 | SMD0603 - R | 1 | 2502484
91R, 1% | SMD Chip Resistor, 91 Ohm, ± 1%, 100 mW, 0603 [1608 Metric], Thick Film, General Purpose | R70, R71 | SMD0603 - R | 2 | 603-RC0603FR-0791RL
6k8, 1% | Res Thick Film 0603 6.8K Ohm 1% 0.1W(1/10W) ±100ppm/C Pad SMD T/R | R73 | SMD0603 - R | 1 | 603-RC0603FR-076K8L
KMR241G | C & K COMPONENTS - KMR241G LFS - SWITCH, SMD, 4N, 0.05A, 32VDC, SPST-NO | SW1 | KMR2 | 1 | 611-KMR241GLFS
MCRH2AF-16R | Rotary Coded Switch Hexadecimal – MCRH Series 10 × 10mm, Through Hole | SW2, SW3, SW4 | MCRH-16 | 3 | 1522033
STM32G030F6P6TR | MCU 32-Bit STM32 ARM Cortex-M0+ RISC 32KB Flash 2V to 3.6V 20-Pin TSSOP T/R | U1 | TSSOP20 | 1 | 511-STM32G030F6P6TR
SIC479ED-T1-GE3 | Switching Voltage Regulators microBUCK 4.5-55V; 3A | U2 | POWERPAK_MLP55-27L_VIS | 1 | 78-SIC479ED-T1-GE3
LDK320M33R | IC REG LINEAR 200MA SOT23-5 | U3 | SOT23-5 | 1 | 511-LDK320M33R
LM27761DSGT | Low-Noise Regulated Inverter with Integrated LDO 8-WSON -40 to 85 | U4 | DFN08 - 2x2mm - os | 1 | 595-LM27761DSGT
NE5532DR | 2-channel, 10-MHz, 26-V output swing, low-noise audio op amp 8-SOIC 0 to 70 | U5, U6, U9 | SOIC08 | 3 | 595-NE5532DR
TCA9539PWR | Remote 16-Bit I2C and SMBus, Low-Power I/O Expander with Interrupt Output, Reset & Config. Register, 1.65 to 5.5 V, -40 to 85 degC, 24-pin TSSOP (PW), Green (RoHS & no Sb/Br) | U7 | PW0024A_M | 1
AD8532ARUZ | Low Cost, 250 mA Output, Single-Supply Amplifiers, DUAL, CMOS, TSSOP, 8PIN, PLASTIC | U8 | TSSOP08 | 1 | 584-AD8532ARUZ-R
SKY13330-397LF | RF Switch SP2T 100MHz to 6GHz 16dB Automotive 12-Pin QFN EP | U10 | QFN50P200X200X100_HS-13N | 1 | 873-SKY13330-397LF
RDA1846 | SINGLE CHIP TRANSCEIVER FOR WALKIE TALKIE | U11 | QFN32-2 | 1
GRF5504 | Amplifier, Power, 0.4–0.5 GHz, 41.0 dB, 34.8 dBm, 3.0 x 3.0 mm QFN-16 | U12 | QFN50P300X300X80_HS-17M - os | 1 | 459-GRF5504
7C-25.000MBA-T | Oscillator XO 25MHz ±25ppm CMOS 60% 3.3V 4-Pin SMD T/R | XO1 | ABRA-ABMM2-4_V | 1 | 717-7C-25.000MBA-T

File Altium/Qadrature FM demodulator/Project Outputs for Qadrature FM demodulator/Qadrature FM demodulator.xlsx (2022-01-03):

Comment | Designator | Footprint | LibRef | Quantity
1u, 25V, X7R | C1, C2, C17, C18 | SMD0603 | CGA3E1X7R1E105K080AC | 4
10k, 1% | R2, R11, R12 | SMD0603 - R | RC0603FR-0710KL | 3
10n, 50V, C0G | C3, C4, C5 | SMD0603 | GRM1885C1H103JA01D | 3
51R, 1% | R4, R9, R13 | SMD0603 - R | CRCW060351R0FKEA | 3
100u, alu, 25V | C11, C15, C16 | WCAP-ATLI_6.3x11x2.5 | 860010473007 | 3
1k2, 1% | R3, R7 | SMD0603 - R | WR06X1201FTL | 2
3k6, 1% | R1, R5 | SMD0603 - R | RC0603FR-073K6L | 2
10u, 25V, X7R | C13, C14 | SMD1206 | GRM31CR71E106KA12L | 2
MCX 73366-0061 | J2, J3 | 73366-0061 | 73366-0061 | 2
1k1, 1% | R8 | SMD0603 - R | MCWR06X1101FTL | 1
1M, 1% | R10 | SMD0603 - R | CRCW06031M00FKEB | 1
1u, 5% | L1 | WE-KI_1008 | 744762310A | 1
2k4, 1% | R6 | SMD0603 - R | RC0603FR-072K4L | 1
6n8, 50V, C0G | C7 | SMD0603 | GRM1885C1H682JA01D | 1
18n, 35V, C0G | C8 | SMD0603 | C1608C0G1V183J080AC | 1
35RAPC4BV4 | J4 | 35RAPC4BV4 | 35RAPC4BV4 | 1
47p, 50V, C0G | C9 | SMD0805 | MC0805N470J500CT | 1
100n, 100V, C0G, 5% | C10 | SMD1206 | GRM31C5C2A104JA01L | 1
100p, 250V, C0G | C6 | SMD0603 | 885342006003 | 1
120p, 50V, C0G | C12 | SMD0603 | CC0603JRNPO9BN121 | 1
61300211121 | J1 | Header 2 2.54mm | 61300211121 | 1
691322110003 | J5 | 691322110003 | 691322110003 | 1
LDK320M33R | U3 | SOT23-5 | LDK320M33R | 1
NE5532DR | U2 | SOIC08 | NE5532DR | 1
SN74LVC86APWR | U1 | TSSOP14 | SN74LVC86APWR | 1

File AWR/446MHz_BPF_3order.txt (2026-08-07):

IND.L1 (5 4) ID=L1 L=1e-08 
CAPQP.CAP1 (4 1) ID=CAP1 F={1e+09} C={1e-12} Q={1000} L=6e-10 R={0} 
IND.L2 (1 2) ID=L2 L=1e-08 
CAPQP.CAP2 (5 0) ID=CAP2 F={1e+09} C={2.02e-11} Q={1000} L=6e-10 R={0} 
CAPQP.CAP3 (6 0) ID=CAP3 F={1e+09} C={2.02e-11} Q={1000} L=6e-10 R={0} 
CAPQP.CAP4 (4 0) ID=CAP4 F={1e+09} C={1.55e-11} Q={1000} L=6e-10 R={0} 
CAPQP.CAP5 (3 0) ID=CAP5 F={1e+09} C={1.55e-11} Q={1000} L=6e-10 R={0} 
CAPQP.CAP6 (2 3) ID=CAP6 F={1e+09} C={1e-12} Q={1000} L=6e-10 R={0} 
IND.L3 (3 6) ID=L3 L=1e-08 
CAPQP.CAP7 (1 0) ID=CAP7 F={1e+09} C={2.2e-11} Q={1000} L=6e-10 R={0} 
CAPQP.CAP8 (2 0) ID=CAP8 F={1e+09} C={2.2e-11} Q={1000} L=6e-10 R={0} 
CAPQP.CAP9 (0 5) ID=CAP9 F={1e+09} C={2.02e-11} Q={1000} L=6e-10 R={0} 
CAPQP.CAP10 (0 6) ID=CAP10 F={1e+09} C={2.02e-11} Q={1000} L=6e-10 R={0} 

PORT.P1 (5) P=1 Z=50 
PORT.P2 (6) P=2 Z=50

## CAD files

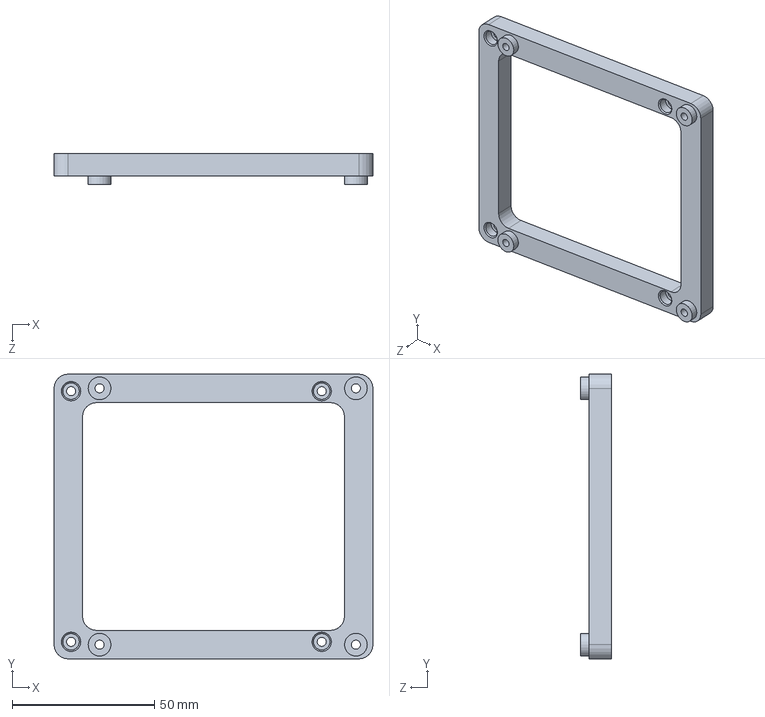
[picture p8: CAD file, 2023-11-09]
Mechanical/Box_for_ver1/Redukce.SLDPRT
112.0 x 100.0 x 11.0 mm

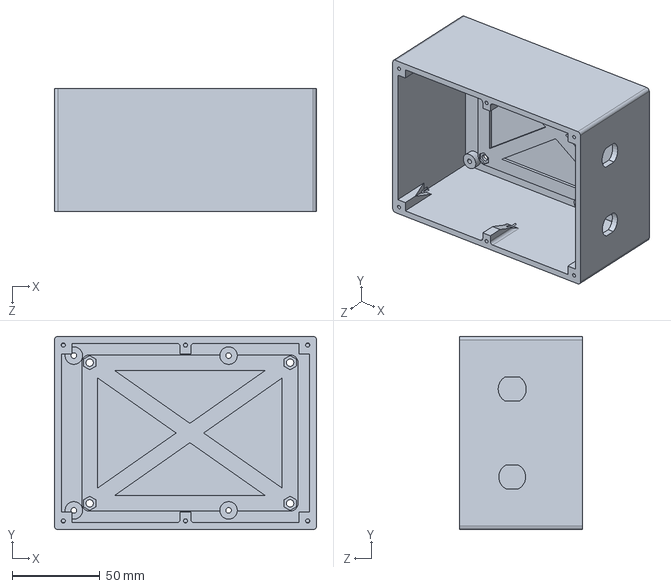
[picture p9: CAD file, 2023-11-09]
Mechanical/Box_for_ver1/bottom.SLDPRT
149.0 x 110.0 x 70.0 mm

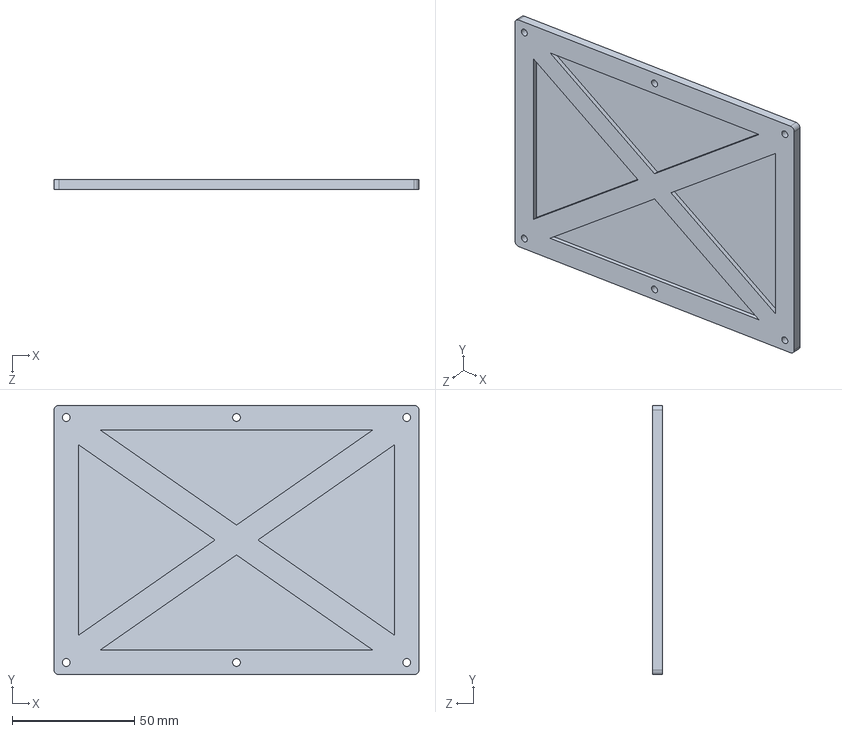
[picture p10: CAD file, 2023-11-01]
Mechanical/Box_for_ver1/Viko.SLDPRT
149.0 x 110.0 x 4.00 mm

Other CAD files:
Mechanical/Box_for_ver1/Redukce.STL
Mechanical/Box_for_ver1/Viko.STL
Mechanical/Box_for_ver1/bottom.STL

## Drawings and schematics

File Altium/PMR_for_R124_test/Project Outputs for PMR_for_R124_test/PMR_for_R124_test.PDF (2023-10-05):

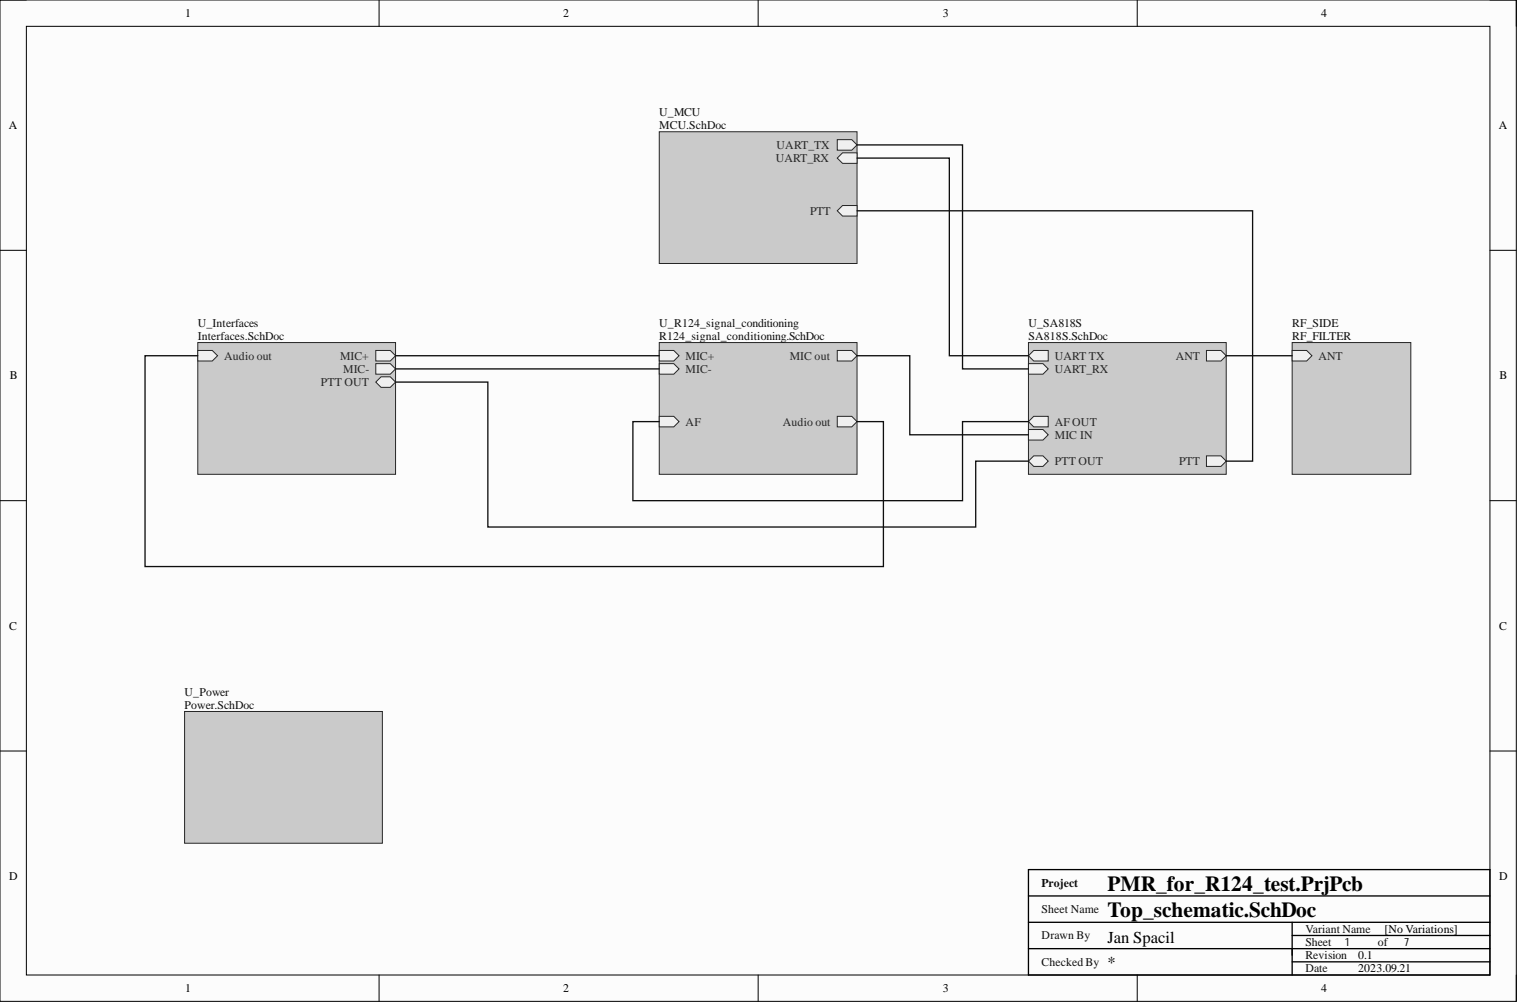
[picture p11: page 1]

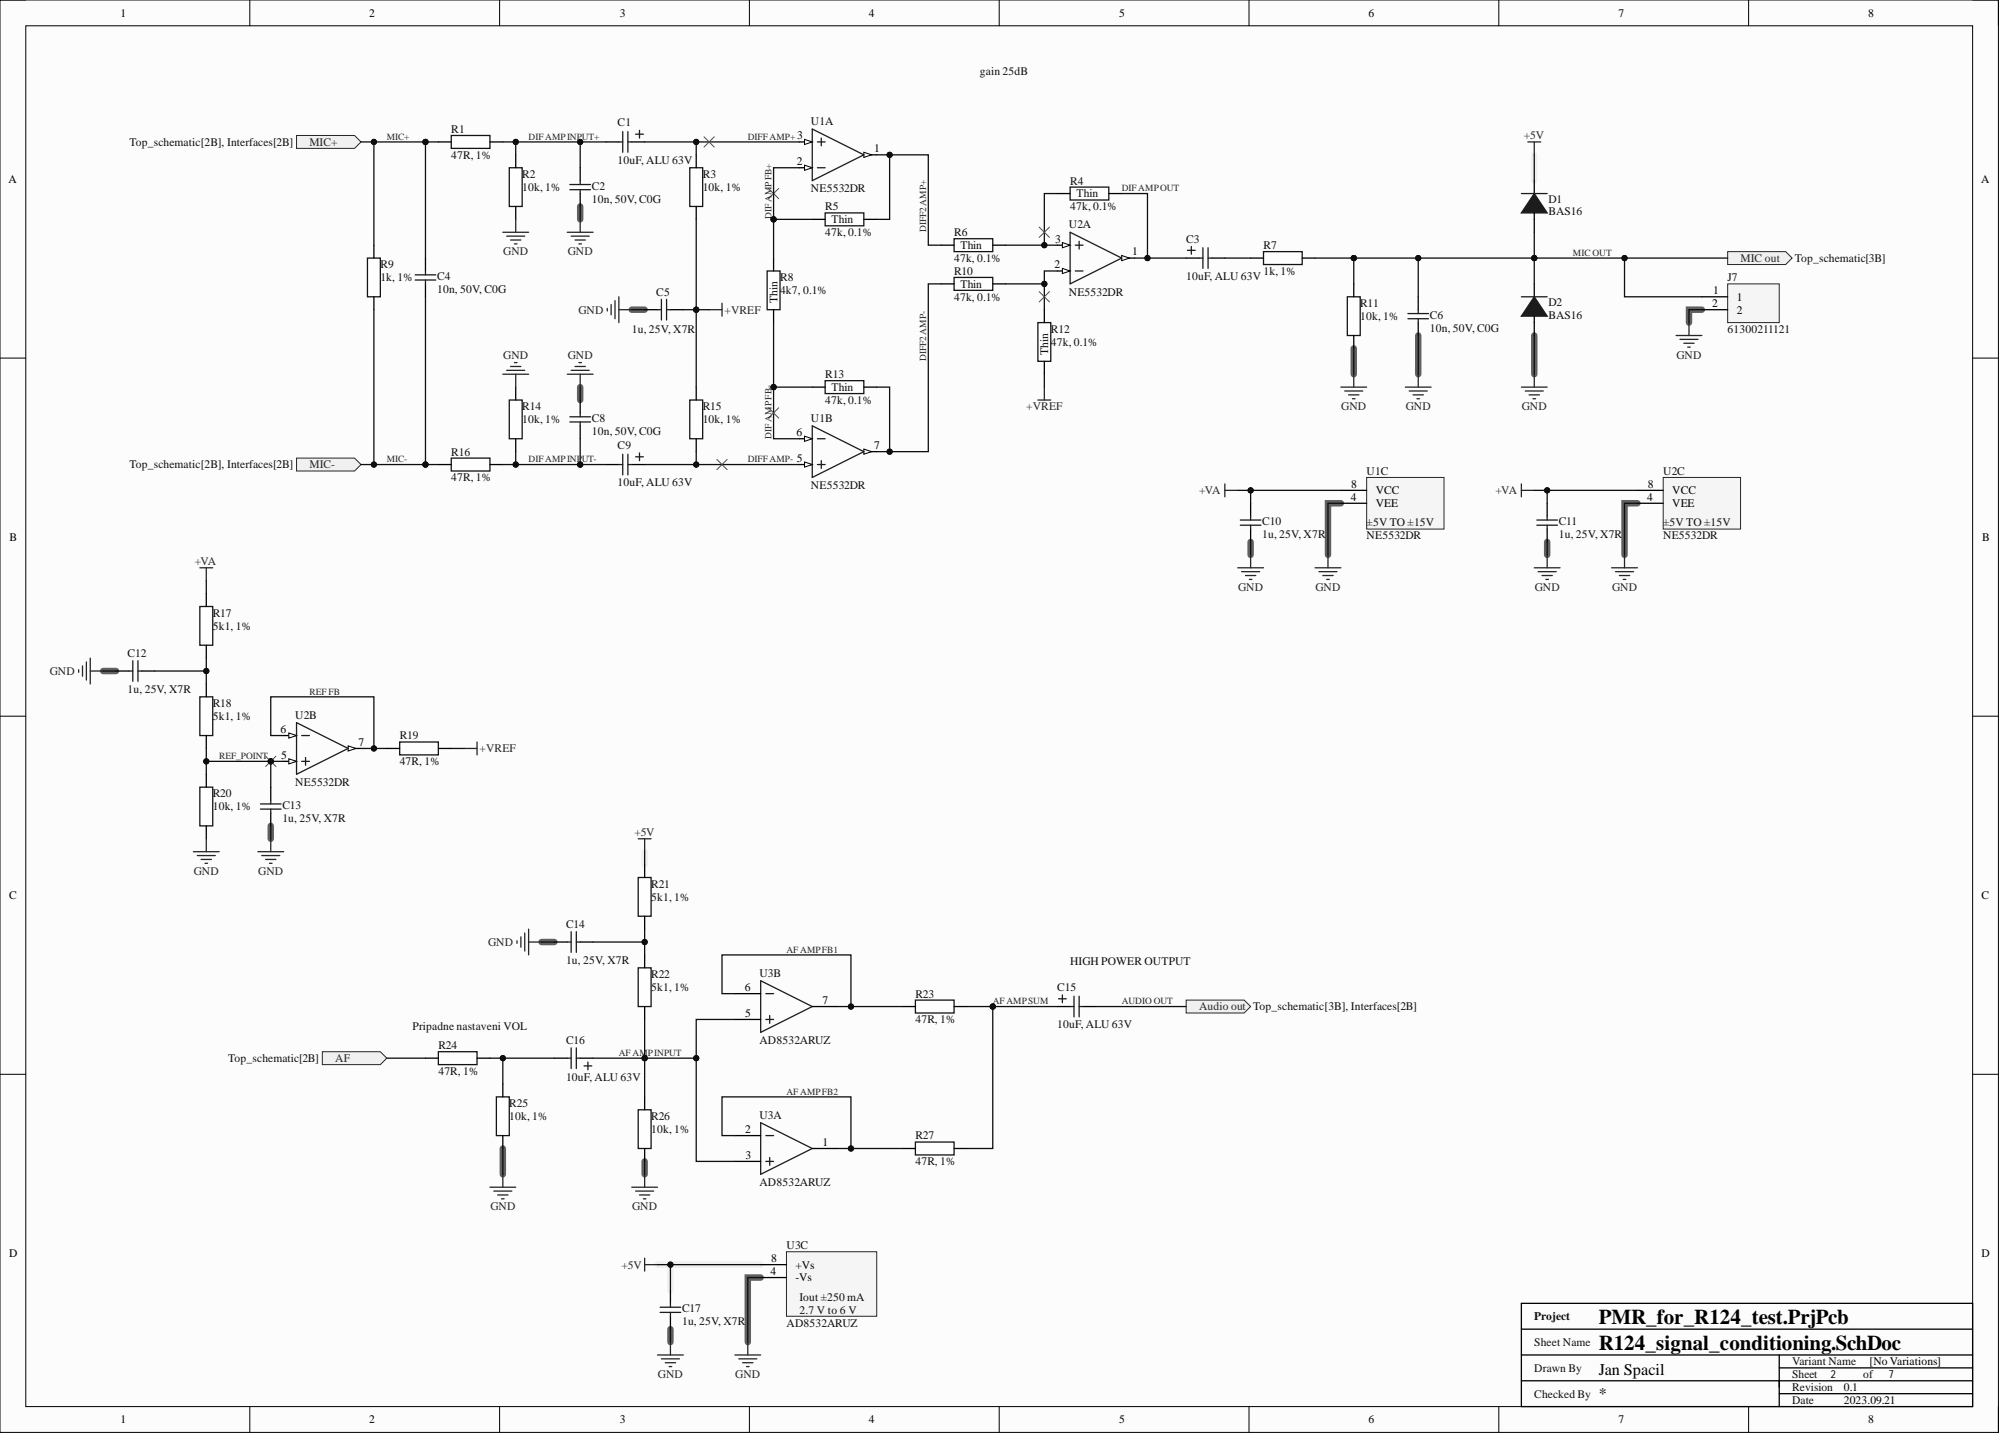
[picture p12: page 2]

DIF AMPFB- DIF AMPFB+

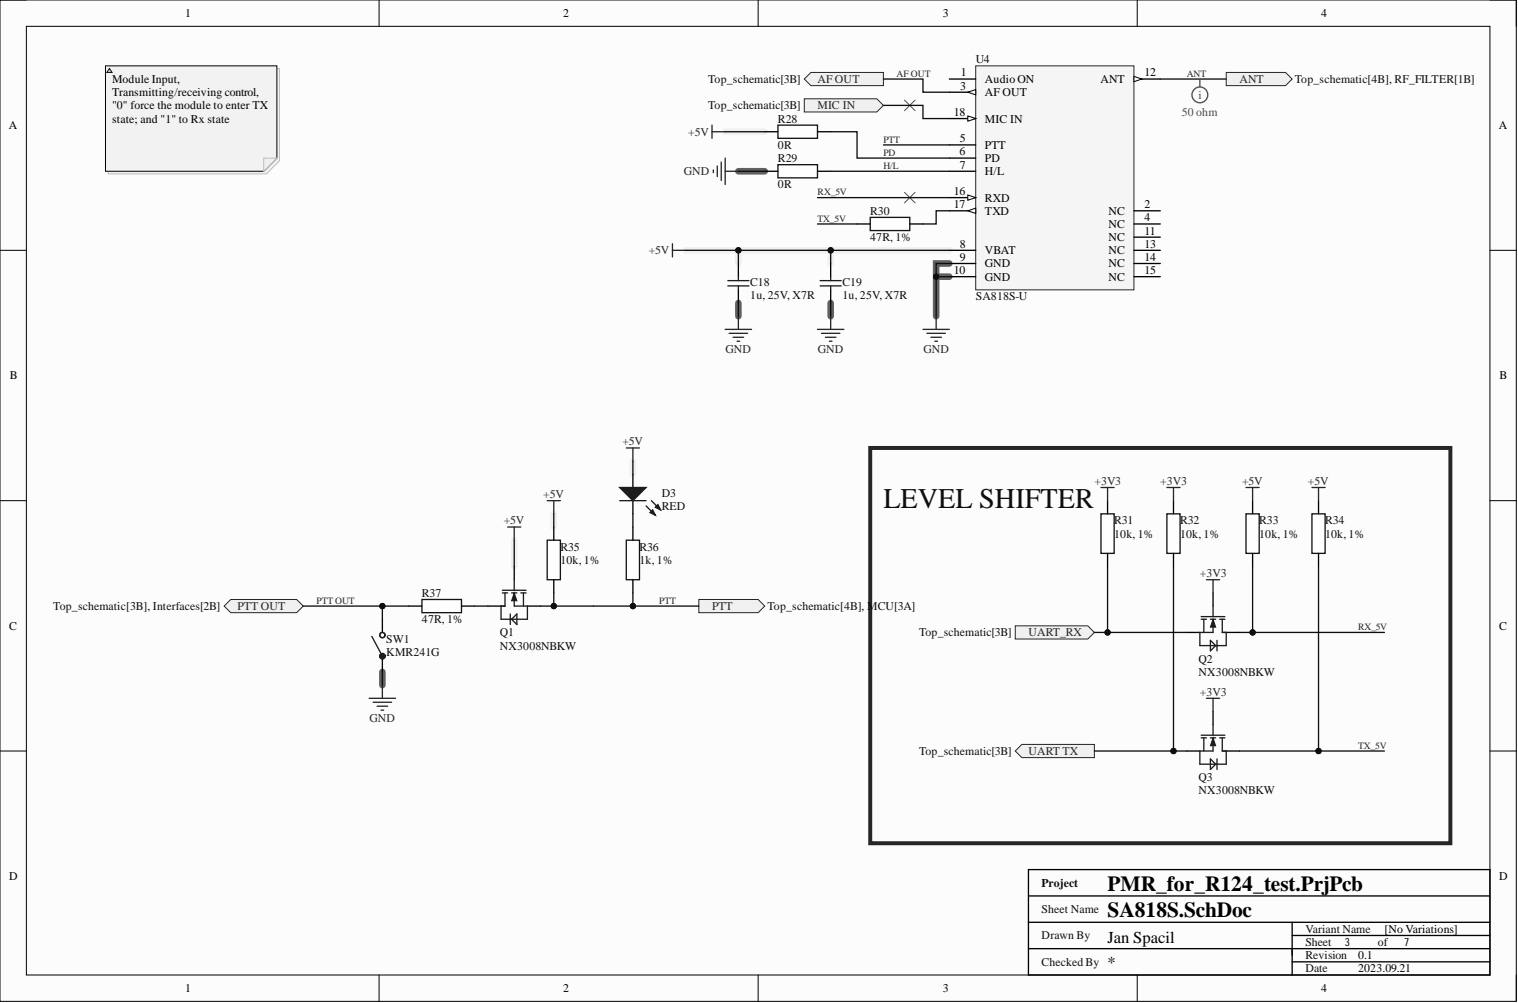
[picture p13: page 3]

Module Input,
Transmitting/receiving control,
"0" force the module to enter TX
state; and "1" to Rx state

TXD 17

GND 9

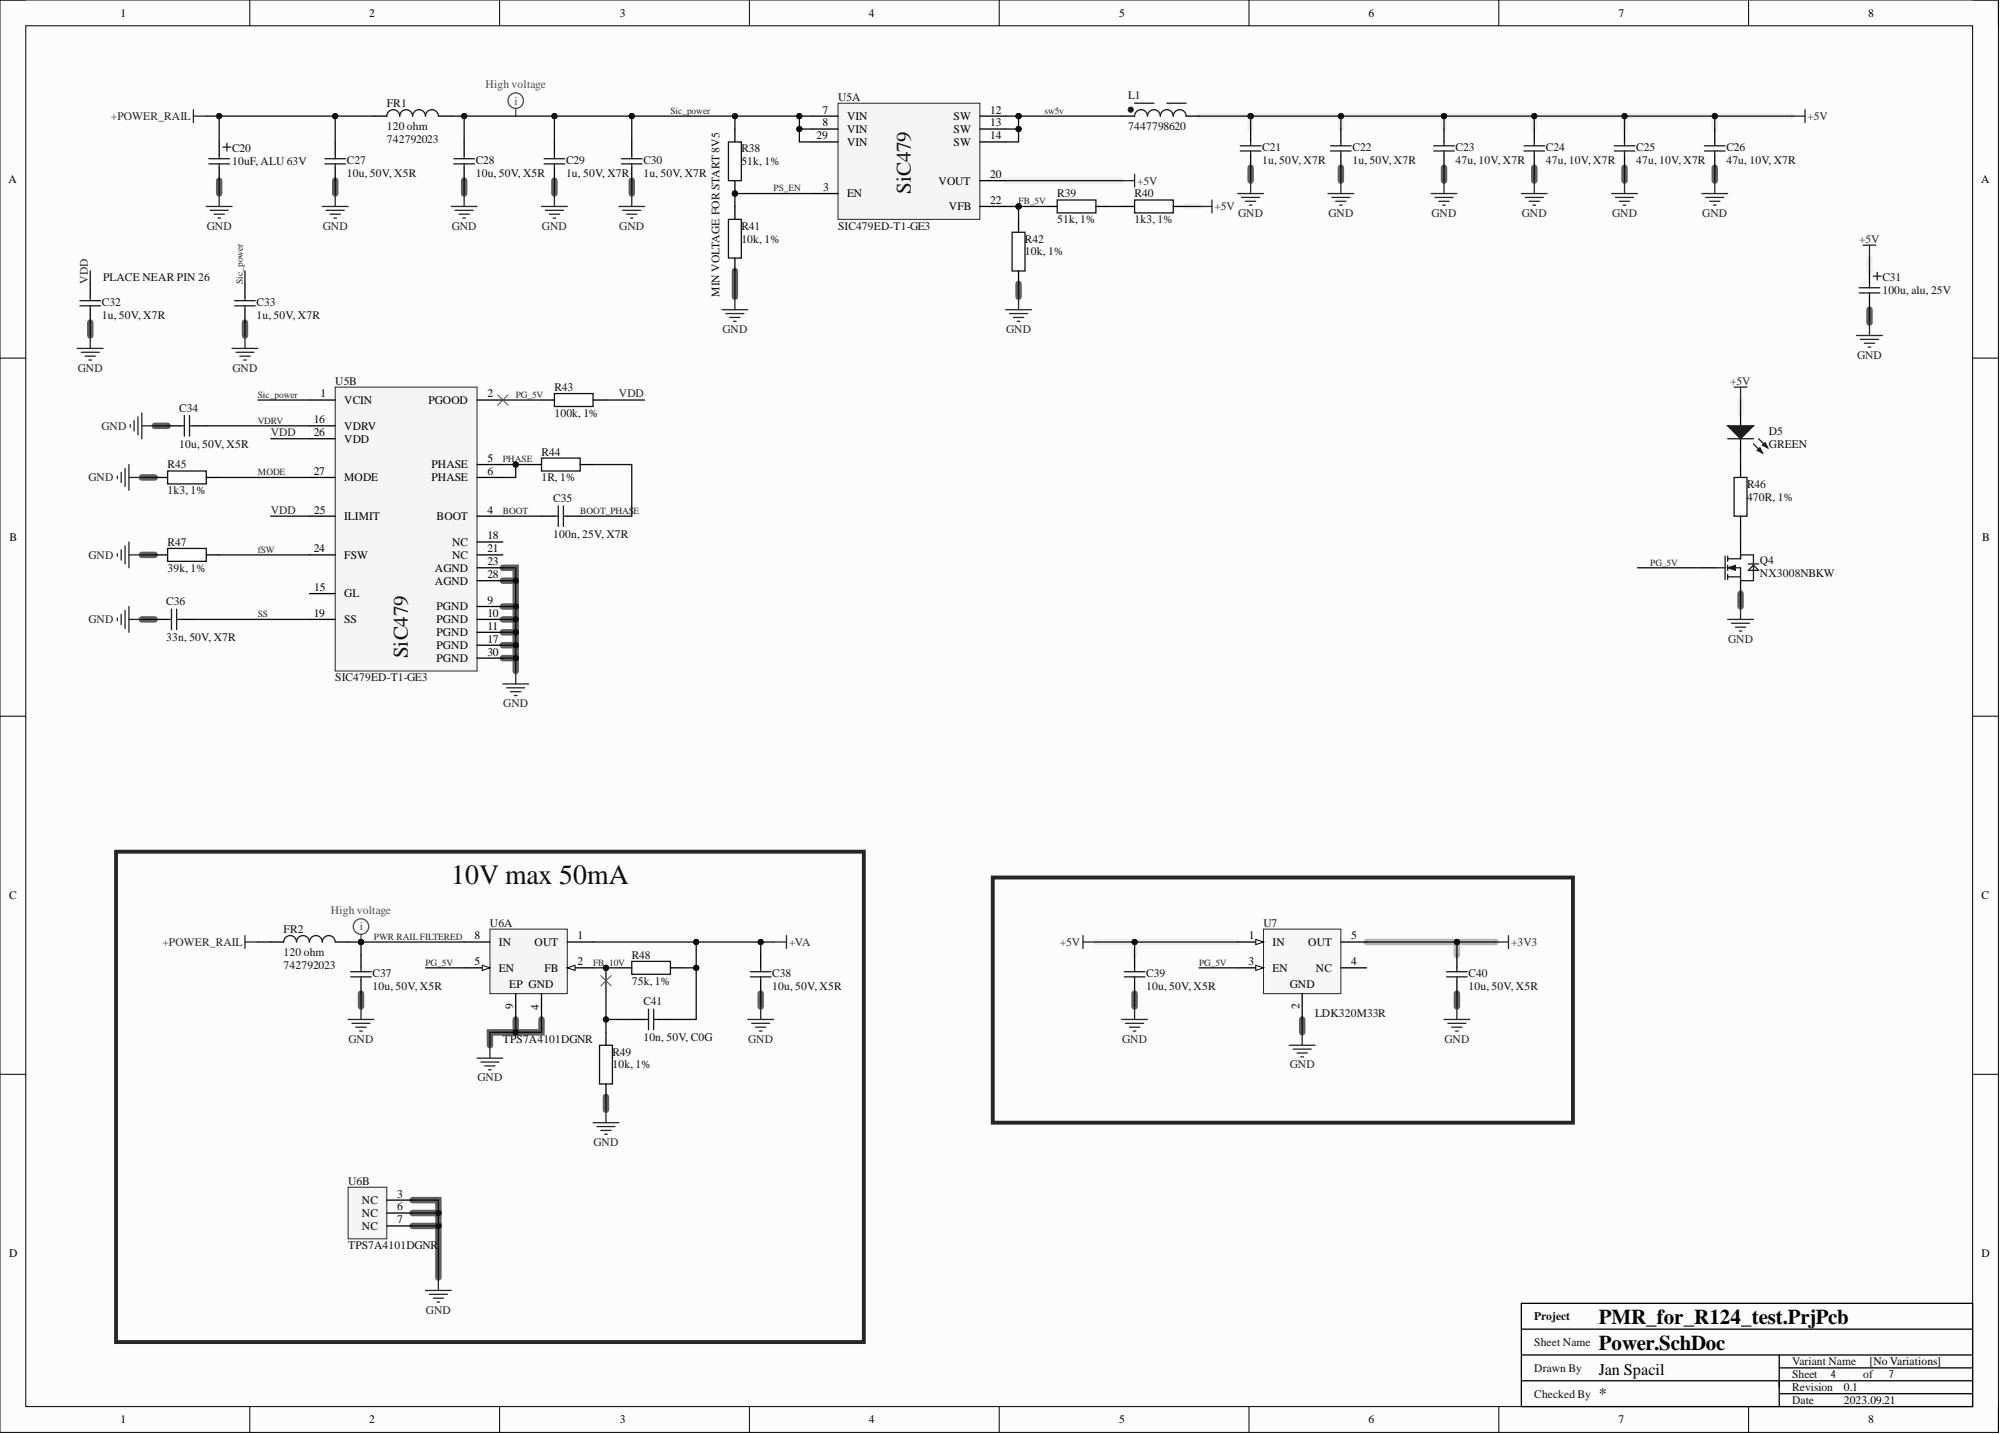
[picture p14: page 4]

Sheet Name Power.SchDoc

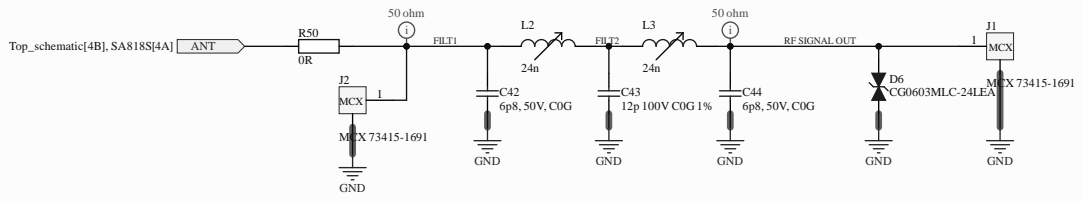
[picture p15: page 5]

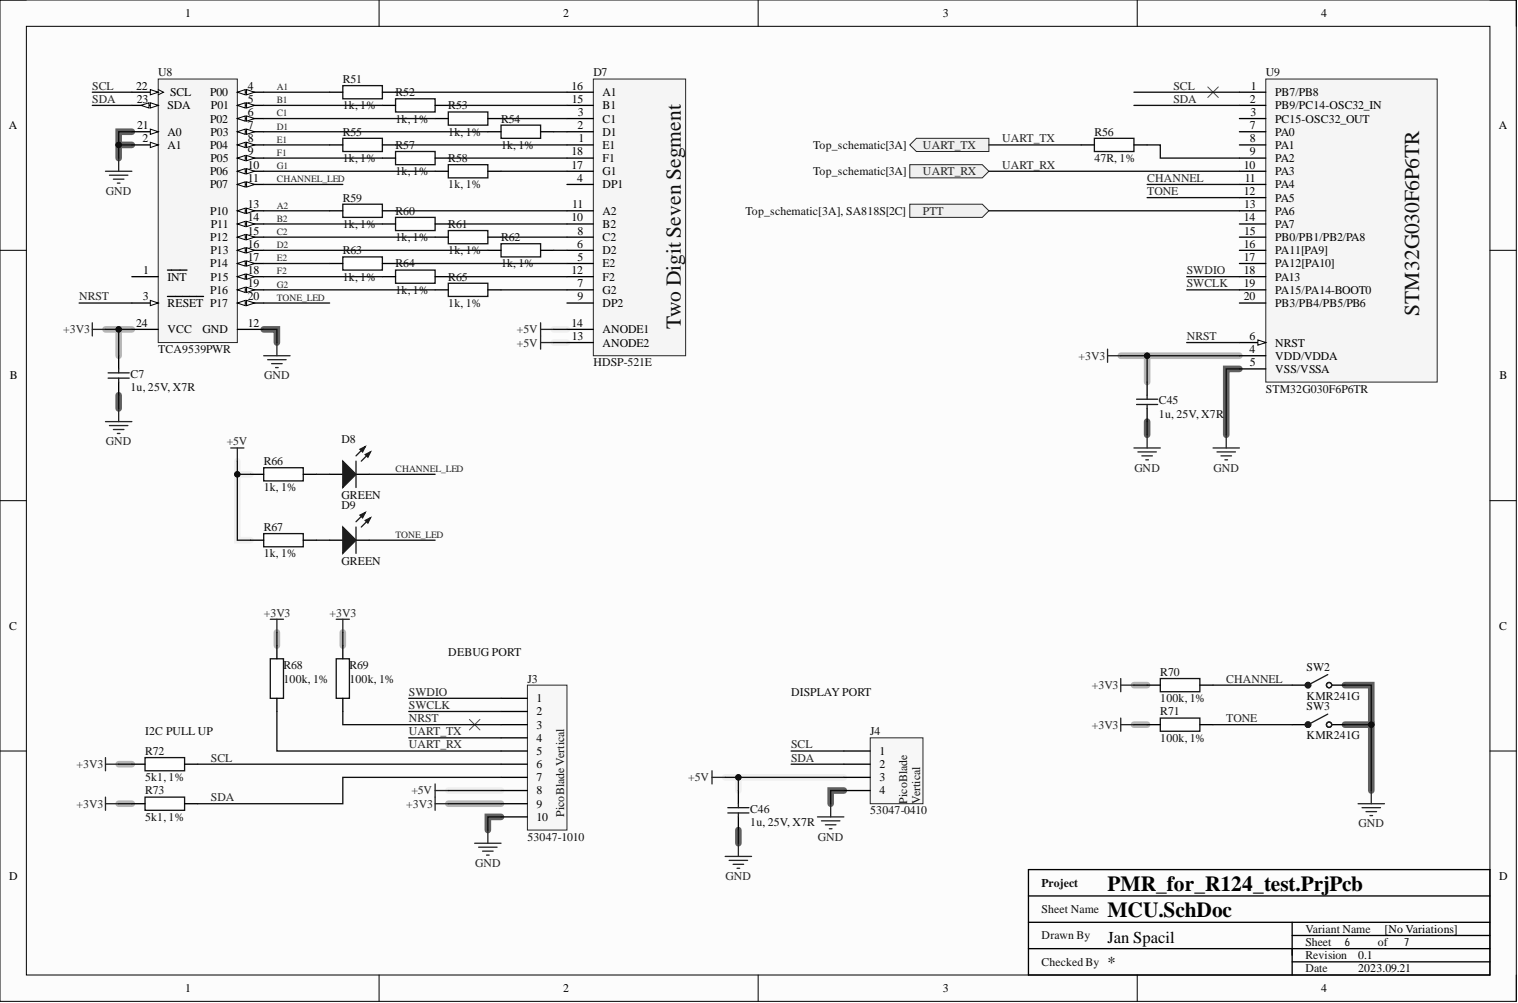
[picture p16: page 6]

Two Digit Seven Segment

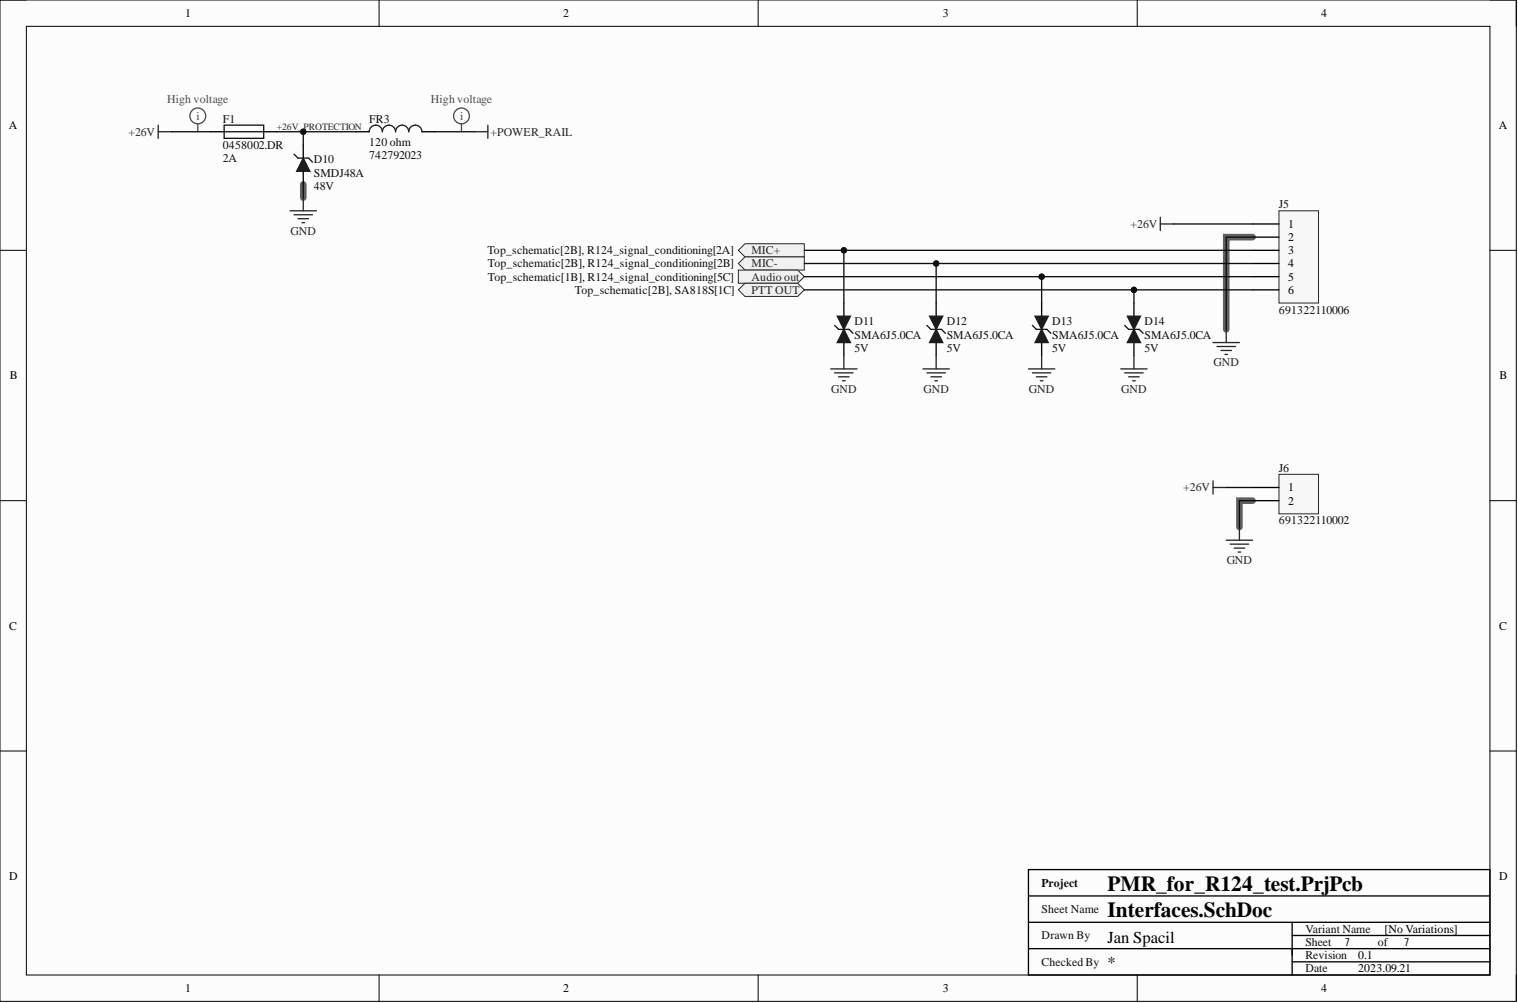
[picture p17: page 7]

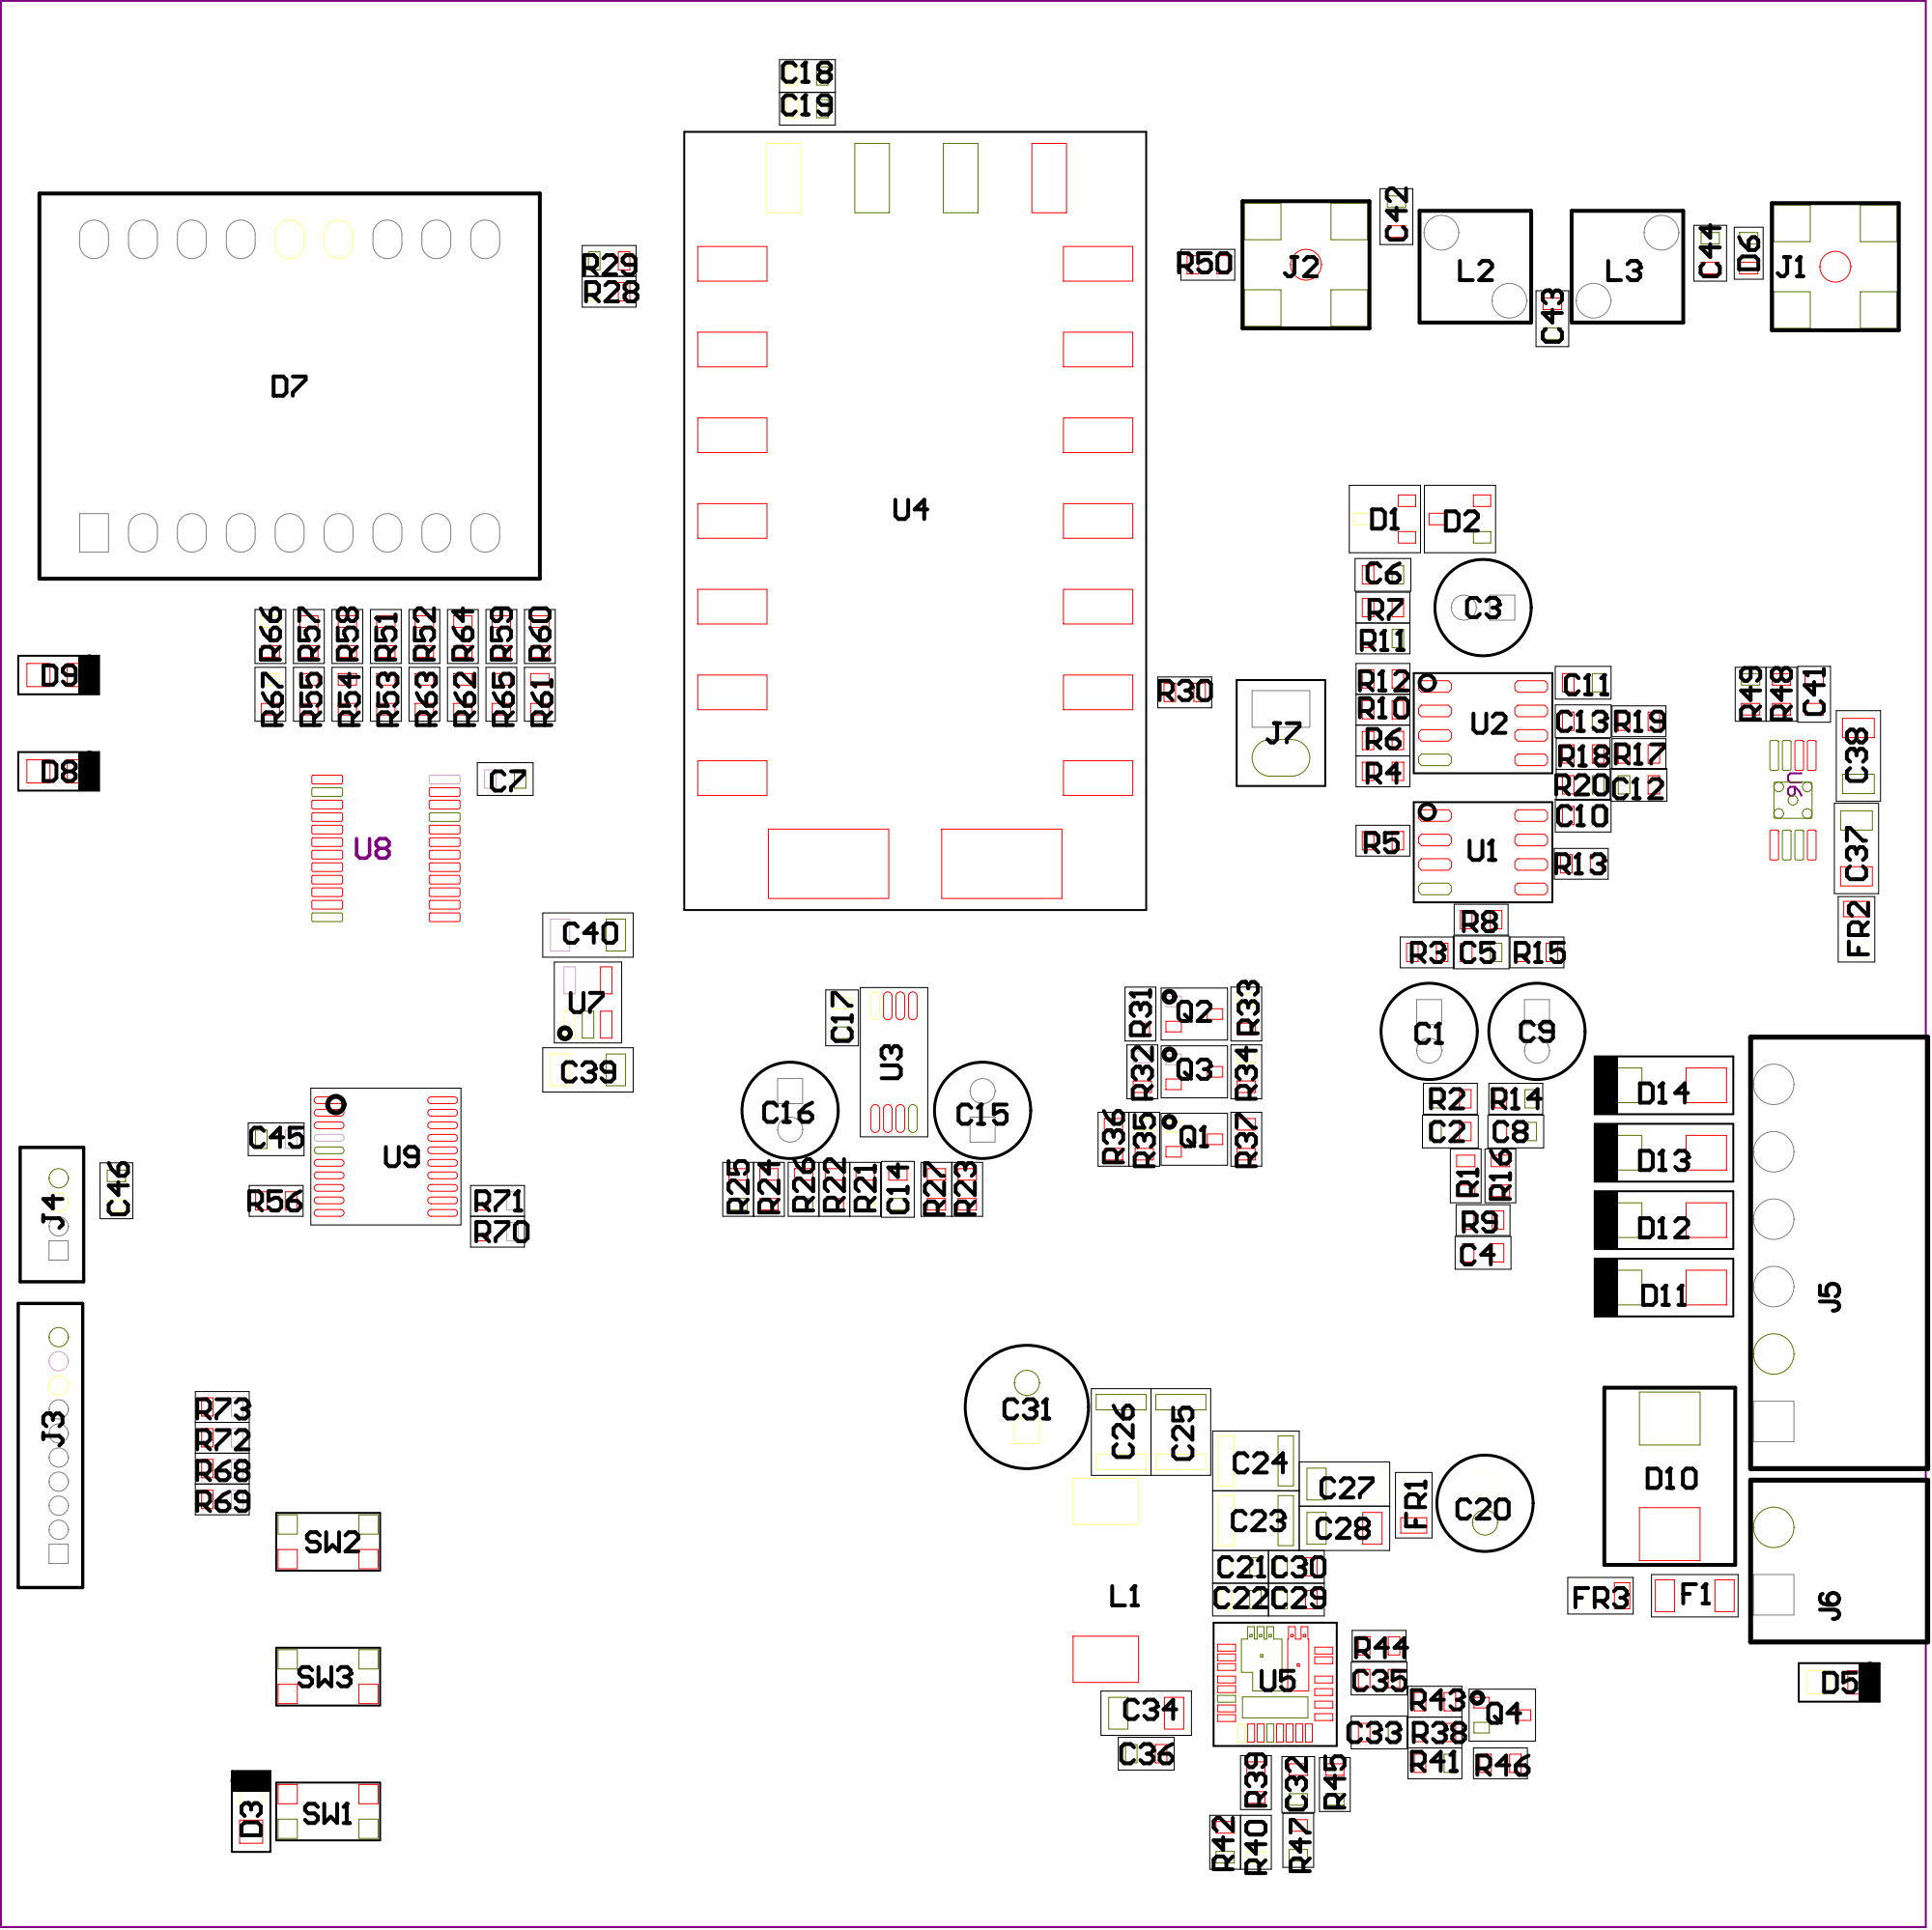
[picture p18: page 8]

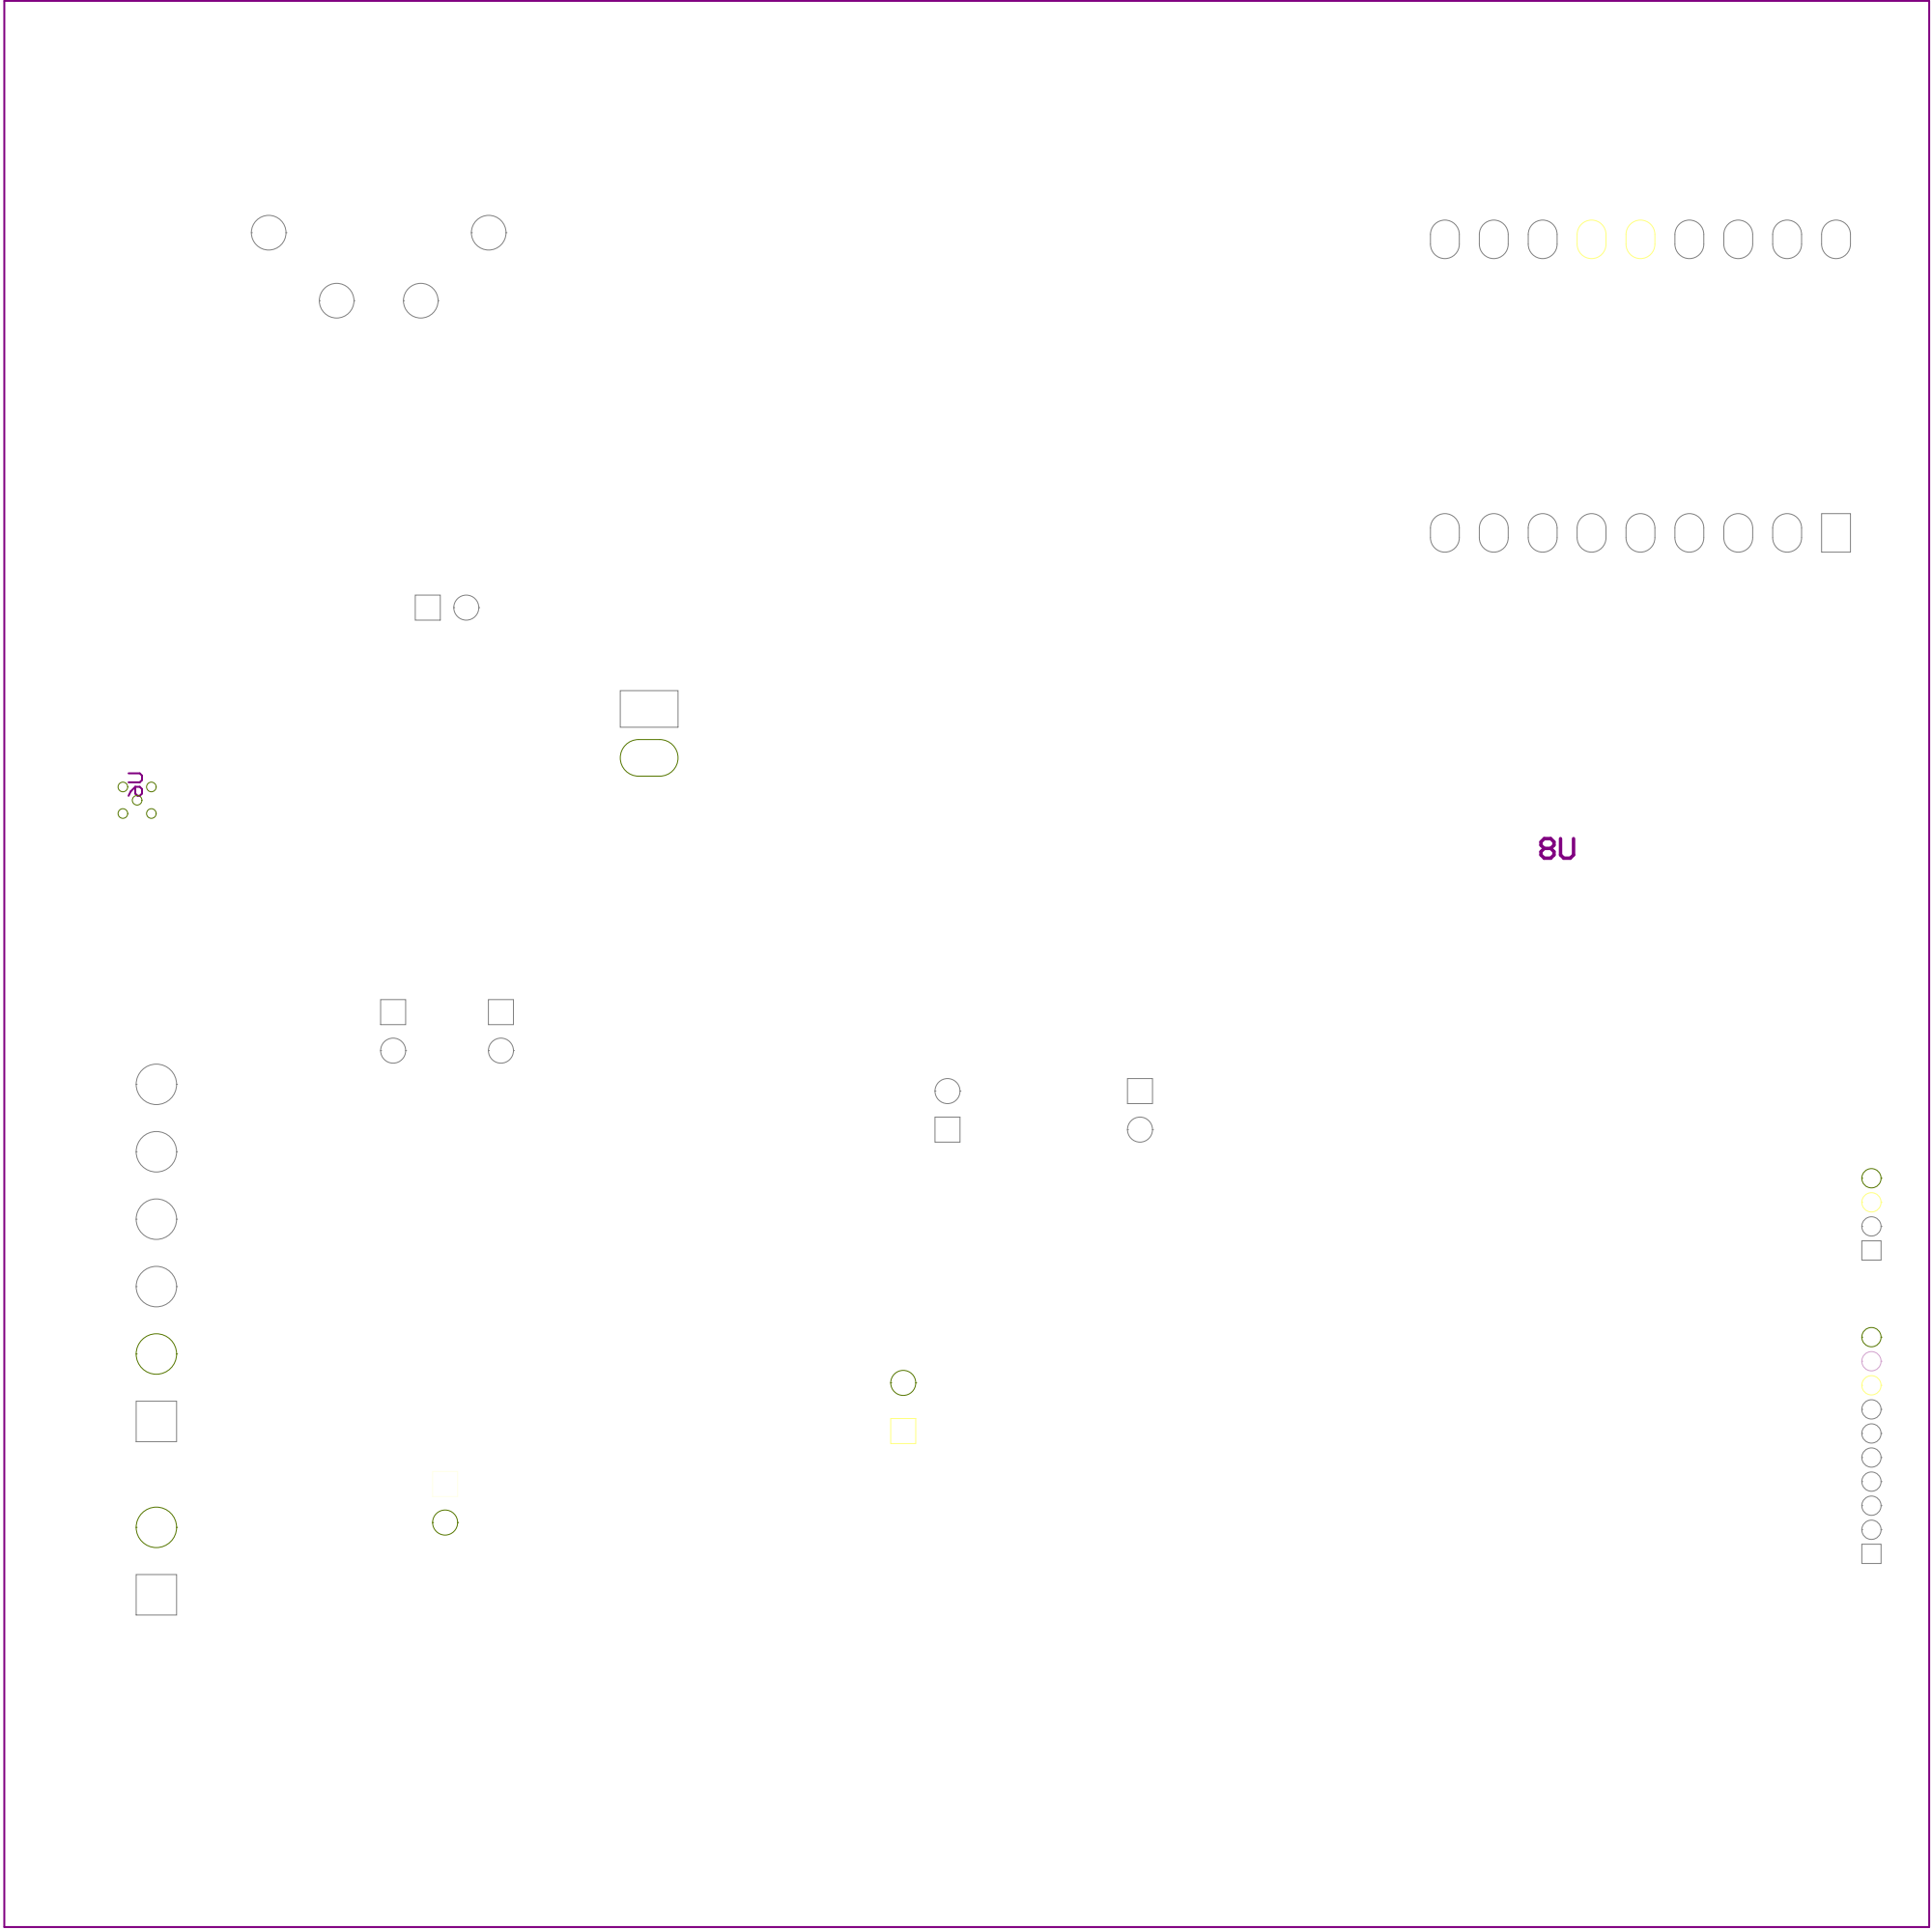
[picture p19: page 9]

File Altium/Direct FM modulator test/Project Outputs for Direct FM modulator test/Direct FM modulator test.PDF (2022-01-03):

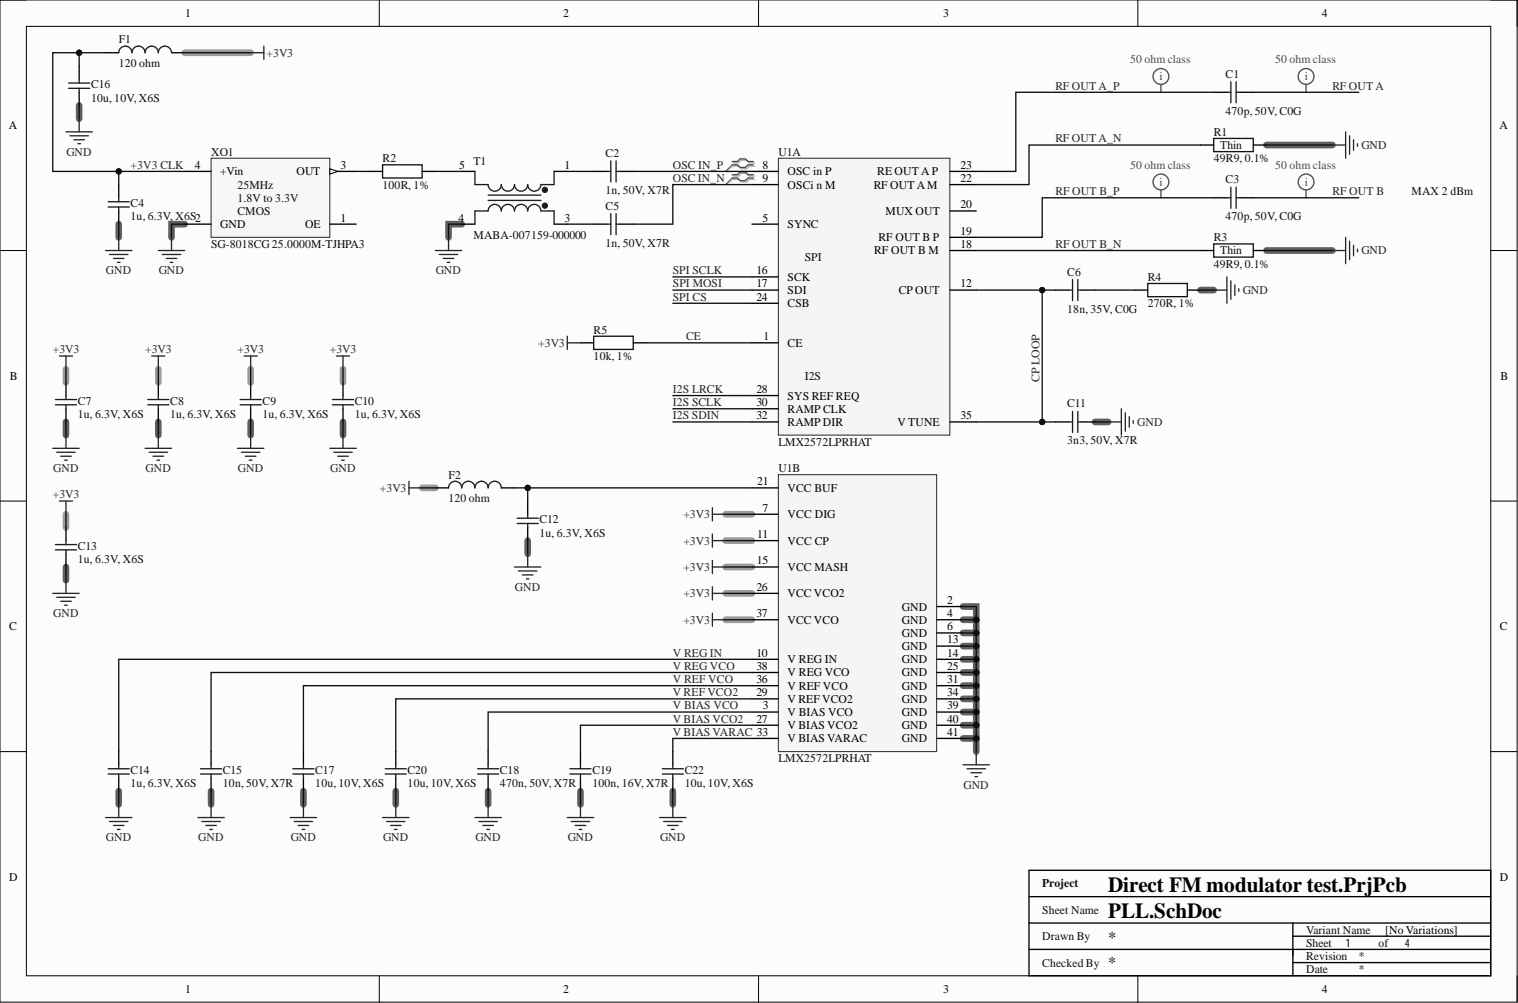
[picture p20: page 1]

Sheet Name PLL.SchDoc

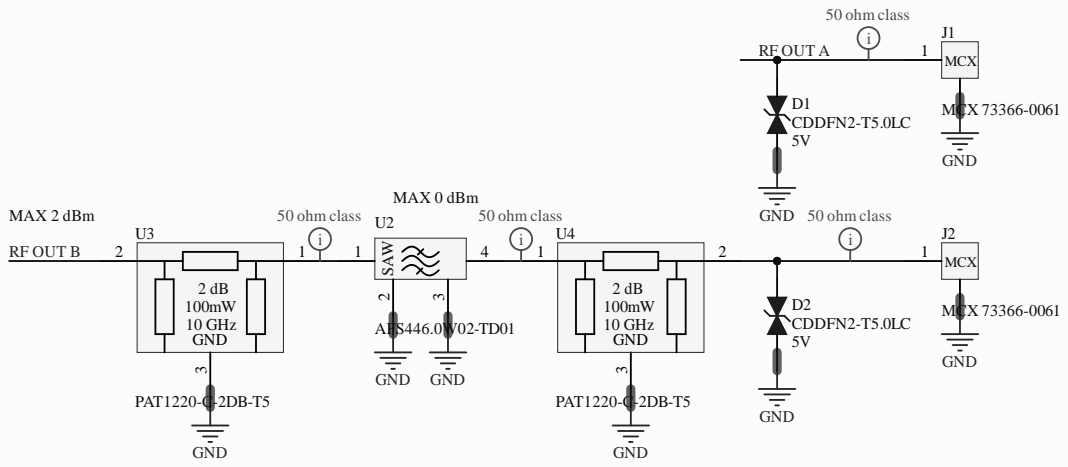
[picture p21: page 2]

Sheet Name Filter and output.SchDoc

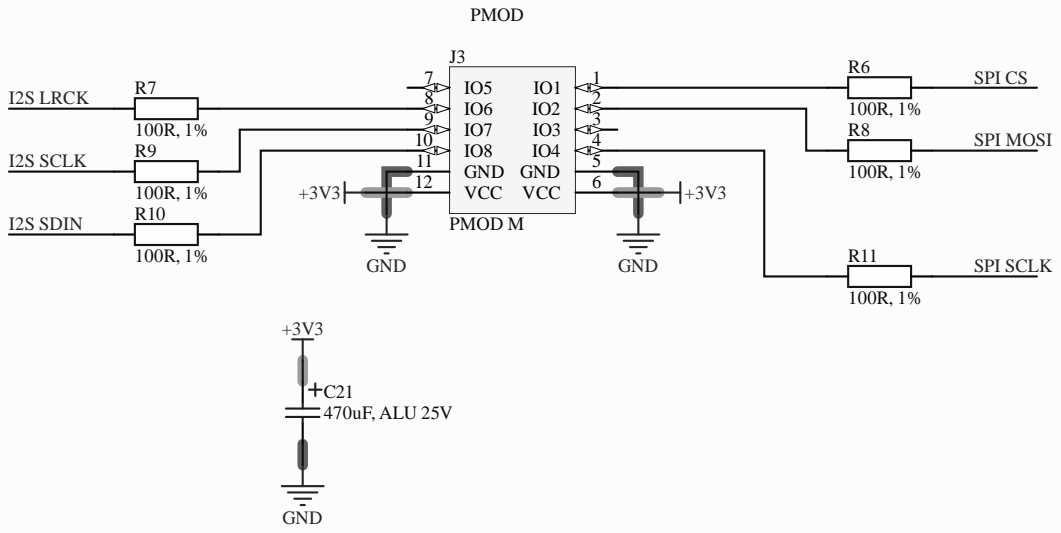
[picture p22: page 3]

1 0 | 4
1 1 | 5
1 2 | 6




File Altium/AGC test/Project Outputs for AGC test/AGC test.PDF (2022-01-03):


Sheet Name MEZIFREKVENCE.SchDoc






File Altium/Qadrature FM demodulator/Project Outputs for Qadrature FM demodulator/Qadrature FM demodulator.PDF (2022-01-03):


Sheet Name Qadrature FM demodulator.SchDoc



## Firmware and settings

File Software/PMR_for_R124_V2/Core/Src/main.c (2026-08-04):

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
/* Includes ------------------------------------------------------------------*/
#include "main.h"

/* USER CODE BEGIN Includes */
#include "rda1846.h"
#include <stdio.h>
#include <string.h>
/* USER CODE END Includes */

I2C_HandleTypeDef hi2c1;
DMA_HandleTypeDef hdma_i2c1_tx;
DMA_HandleTypeDef hdma_i2c1_rx;

UART_HandleTypeDef huart2;
DMA_HandleTypeDef hdma_usart2_tx;

/* USER CODE BEGIN PV */
volatile uint8_t current_channel = 4; // Index 3 odpovídá PMR kanálu 4 (446.043750 MHz)
volatile uint8_t current_ctcss = 5;  // Index 25 odpovídá CTCSS tónu 156.7 Hz
volatile uint8_t is_tx = 0;           // Stavový příznak transceiveru (0 = RX, 1 = TX)

RDA1846_Reg30_t rda_settings = {0};
RDA1846_ctcss ctcss_settings = {0};
/* USER CODE END PV */

void SystemClock_Config(void);
static void MX_GPIO_Init(void);
static void MX_DMA_Init(void);
static void MX_I2C1_Init(void);
static void MX_USART2_UART_Init(void);
/* USER CODE BEGIN PFP */
void Debug_Print(const char *msg);
/* USER CODE END PFP */

/* USER CODE BEGIN 0 */
void Debug_Print(const char *msg) {
    HAL_UART_Transmit(&huart2, (uint8_t *)msg, strlen(msg), 100);
}
/* USER CODE END 0 */

int main(void)
{
  HAL_Init();
  SystemClock_Config();
  MX_GPIO_Init();
  MX_DMA_Init();
  MX_I2C1_Init();
  MX_USART2_UART_Init();

  /* USER CODE BEGIN 2 */
  char debug_msg[128];
  Debug_Print("\r\n=======================================\r\n");
  Debug_Print("--- PMR446 Transceiver Booting ---\r\n");
  Debug_Print("=======================================\r\n");

  rda_settings.bits.pdn_reg = 1;
  rda_settings.bits.channel_mode = 0;
  rda_settings.bits.sq_on = 1;
  rda_settings.bits.chip_cal_en = 1;    // Povolení kalibrace VCO
  rda_settings.bits.others = 1;         // Nastaví bit 14 na 1 (Režim 26 MHz)

  ctcss_settings.tx_CTCSS = RDA1846_CTCSS_INNER_CTCSS_EN;
  ctcss_settings.rx_CTCSS = RDA1846_CTCSS_INNER_CTCSS_EN;
  ctcss_settings.tone = CTCSS_Tones[current_ctcss];

  HAL_StatusTypeDef i2c_stat = RDA1846_WriteRegister(0x30, rda_settings.value);
  if (i2c_stat != HAL_OK) {
      Debug_Print("[ERROR] I2C komunikace s RDA1846 selhala!\r\n");
  } else {
      Debug_Print("[OK] I2C komunikace navazana.\r\n");
  }

  Debug_Print("[INFO] Nahravam tovarni inicializacni sekvenci (DSP/AGC/PLL)...\r\n");
  RDA1846_Init();

  RDA1846_SetReferenceClock(25000);

  uint32_t target_freq = PMR446_Frequencies[current_channel];
  snprintf(debug_msg, sizeof(debug_msg), "[INFO] Nastavuji frekvenci: %lu Hz (Kanal %d)\r\n", target_freq, current_channel + 1);
  Debug_Print(debug_msg);
  RDA1846_SetFrequency(target_freq);

  // Nastavení Squelch hystereze (Otevře při -113 dBm, Zavře při -116 dBm)
    RDA1846_SetSquelchThresholds(-113, -116);

  HAL_GPIO_WritePin(PA_BIAS_ON_GPIO_Port, PA_BIAS_ON_Pin, GPIO_PIN_RESET);
  RDA1846_SetRxMode(&rda_settings, &ctcss_settings);
  is_tx = 0;
  Debug_Print("[INFO] Inicializace dokoncena. System prechazi do RX rezimu.\r\n");

  /* USER CODE END 2 */

  /* Infinite loop */
  /* USER CODE BEGIN WHILE */

  static uint32_t last_debounce_time = 0;
  static uint32_t last_telemetry_time = 0;
  static GPIO_PinState last_ptt_state = GPIO_PIN_SET;
  static GPIO_PinState debounced_ptt_state = GPIO_PIN_SET;

  while (1)
  {
    /* USER CODE END WHILE */

    /* USER CODE BEGIN 3 */

    // --- 1. Vyhodnoceni PTT (Debounce) ---
    GPIO_PinState current_ptt_state = HAL_GPIO_ReadPin(PTT_GPIO_Port, PTT_Pin);

    if (current_ptt_state != last_ptt_state) {
        last_debounce_time = HAL_GetTick();
    }

    if ((HAL_GetTick() - last_debounce_time) > 20) {
        if (current_ptt_state != debounced_ptt_state) {
            debounced_ptt_state = current_ptt_state;

            if (debounced_ptt_state == GPIO_PIN_RESET && !is_tx) {
                Debug_Print("[ACTION] PTT stisknuto. Prepinam do TX...\r\n");
                HAL_GPIO_WritePin(PA_BIAS_ON_GPIO_Port, PA_BIAS_ON_Pin, GPIO_PIN_SET);
                HAL_Delay(10);
                RDA1846_SetTxMode(&rda_settings, &ctcss_settings);
                is_tx = 1;
                Debug_Print("[INFO] TX rezim aktivni.\r\n");
            }
            else if (debounced_ptt_state == GPIO_PIN_SET && is_tx) {
                Debug_Print("[ACTION] PTT uvolneno. Prepinam do RX...\r\n");
                RDA1846_SetRxMode(&rda_settings, &ctcss_settings);
                HAL_Delay(10);
                HAL_GPIO_WritePin(PA_BIAS_ON_GPIO_Port, PA_BIAS_ON_Pin, GPIO_PIN_RESET);
                is_tx = 0;
                Debug_Print("[INFO] RX rezim aktivni.\r\n");
            }
        }
    }
    last_ptt_state = current_ptt_state;

    // --- 2. Kontinualni telemetrie (RSSI a SQ stav) ---
    if (!is_tx && (HAL_GetTick() - last_telemetry_time) > 500) {
        last_telemetry_time = HAL_GetTick();

        uint16_t raw_rssi = RDA1846_ReadRSSI();
        uint16_t flags = RDA1846_ReadFlags();

        // Konverze surové hodnoty z registru 0x5F (bity 9:0) na dBm dle datasheetu
        int16_t rssi_dbm = (raw_rssi / 8) - 135;

        snprintf(debug_msg, sizeof(debug_msg), "[TELEMETRY] RSSI: %d dBm (raw: %u), Flags: 0x%04X\r\n", rssi_dbm, raw_rssi, flags);
        Debug_Print(debug_msg);

        if (flags & FLAG_SQUELCH_OPEN) {
            Debug_Print(" >>> SQUELCH OTEVREN (Nosna detekovana) <<<\r\n");
        }
        if (flags & FLAG_CTCSS_DETECTED) {
            Debug_Print(" >>> CTCSS TON DETEKOVÁN <<<\r\n");
        }
    }
  }
  /* USER CODE END 3 */
}


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


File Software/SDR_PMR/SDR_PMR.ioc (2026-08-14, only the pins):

Mcu.UserName=STM32H725RGVx
PA0.Signal=UART4_TX
PA1.Signal=UART4_RX
PA11.Signal=USB_OTG_HS_DM
PA12.Signal=USB_OTG_HS_DP
PA13(JTMS/SWDIO).Signal=DEBUG_JTMS-SWDIO
PA14(JTCK/SWCLK).Signal=DEBUG_JTCK-SWCLK
PA15(JTDI).Signal=I2S3_WS
PA2.GPIO_Label=PTT_TO_MCU
PA2.Signal=GPIO_Input
PA3.GPIO_Label=PTT_LED
PA3.Signal=GPIO_Output
PA4.Signal=I2S1_WS
PA5.Signal=I2S1_CK
PA6.Signal=I2S1_SDI
PA7.Signal=I2S1_SDO
PA8.Signal=USB_OTG_HS_SOF
PA9.Signal=USB_OTG_HS_VBUS
PB10.Signal=I2S2_CK
PB12.Signal=I2S2_WS
PB13.Signal=UART5_TX
PB14.Signal=I2S2_SDI
PB15.Signal=I2S2_SDO
PB2.Signal=I2S3_SDO
PB3(JTDO/TRACESWO).GPIO_Label=SPI6_nCS
PB3(JTDO/TRACESWO).Signal=GPIO_Output
PB4(NJTRST).Signal=SPI6_MISO
PB5.Signal=SPI6_MOSI
PB6.Signal=I2C1_SCL
PB7.Signal=I2C1_SDA
PB8.GPIO_Label=CB_nIRQ
PB8.Signal=GPXTI8
PB9.GPIO_Label=CB_nRESET
PB9.Signal=GPIO_Output
PC0.GPIO_Label=RADIO_RESET
PC0.Signal=GPIO_Input
PC1.GPIO_Label=PA_BIAS_ON
PC1.Signal=GPIO_Output
PC10.Signal=I2S3_CK
PC11.Signal=I2S3_SDI
PC12.Signal=SPI6_SCK
PC4.GPIO_Label=RX_BAND
PC4.Signal=GPIO_Output
PC5.GPIO_Label=FILTER_TUNE
PC5.Signal=GPIO_Output
PC6.Signal=S_TIM3_CH1
PC7.GPIO_Label=LNA_ON
PC7.Signal=GPIO_Output
PC9.Signal=I2S_CKIN
PD2.Signal=UART5_RX
PH0-OSC_IN.Signal=RCC_OSC_IN

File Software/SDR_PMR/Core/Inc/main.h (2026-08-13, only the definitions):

#define RADIO_RESET_Pin GPIO_PIN_0
#define RADIO_RESET_GPIO_Port GPIOC
#define PA_BIAS_ON_Pin GPIO_PIN_1
#define PA_BIAS_ON_GPIO_Port GPIOC
#define PTT_TO_MCU_Pin GPIO_PIN_2
#define PTT_TO_MCU_GPIO_Port GPIOA
#define PTT_LED_Pin GPIO_PIN_3
#define PTT_LED_GPIO_Port GPIOA
#define RX_BAND_Pin GPIO_PIN_4
#define RX_BAND_GPIO_Port GPIOC
#define FILTER_TUNE_Pin GPIO_PIN_5
#define FILTER_TUNE_GPIO_Port GPIOC
#define LNA_ON_Pin GPIO_PIN_7
#define LNA_ON_GPIO_Port GPIOC
#define SPI6_nCS_Pin GPIO_PIN_3
#define SPI6_nCS_GPIO_Port GPIOB
#define CB_nIRQ_Pin GPIO_PIN_8
#define CB_nIRQ_GPIO_Port GPIOB
#define CB_nRESET_Pin GPIO_PIN_9
#define CB_nRESET_GPIO_Port GPIOB

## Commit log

2021-11-15 Add direct fm modulator skeleton
    [Connectors.SchDoc, Direct FM modulator test.PrjPcb, Filter and output.SchDoc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]
2021-11-17 LMX2572 PMOD, changed schematic and created PCB
    [Connectors.SchDoc, Direct FM modulator test.PcbDoc, Direct FM modulator test.PrjPcb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]
2021-11-17 Coplited DRC
    [Connectors.SchDoc, Direct FM modulator test.PcbDoc, Filter and output.SchDoc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]
2021-11-18 Filter datasheet
2021-11-20 Start filter test board
    [Calkit.SchDoc, Direct FM modulator test.PcbDoc, Filter board test.PrjPcb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]
2021-11-21 Filter and IF test board
    [Calkit.SchDoc, Filter board test.PcbDoc, Filter board test.PrjPcb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]
2021-11-27 Filter test board finished
    [Calkit.SchDoc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]
2021-11-27 AGC test board finished
    [AGC test.PcbDoc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]
2021-11-28 Quadrature FM demodulator test board
    [Qadrature FM demodulator.PrjPcb, Qadrature FM demodulator.SchDoc]
2021-11-30 Quadrature FM demodulator skoro dodelane
    [Qadrature FM demodulator.PcbDoc, Qadrature FM demodulator.PrjPcb, Qadrature FM demodulator.SchDoc]
2021-12-01 Filter changet do 0.8mm substrate
    [Filter board test.PcbDoc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]
2021-12-01 Quadrature demodulator finished
    [Qadrature FM demodulator.PcbDoc, Qadrature FM demodulator.PrjPcb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]
2021-12-08 Add documentation
    [Filter board test.PrjPcb, Qadrature FM demodulator.PrjPcb]
2021-12-10 Gerber files
    [Direct FM modulator test.PrjPcb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]
2022-01-03 Reciever test
    [AF AMP.SchDoc, AGC test.PcbDoc, AGC test.xlsx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]
2022-01-04 Prijimac update
    [Control panel.SchDoc, IF 2.SchDoc, RF_IN.SchDoc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]
2022-01-16 pcb layout, schematic update
    [AF AMP.SchDoc, Control panel.SchDoc, DETECTOR.SchDoc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]
2022-01-19 Uprava vygenerovani ioc file pro stm32
2022-01-29 Component placement complet
    [DETECTOR.SchDoc, IF 1.SchDoc, TOP.SchDoc]
2022-01-30 PCB final
    [IF 1.SchDoc, Power.SchDoc, RF_IN.SchDoc]
2022-11-28 PMR rx test board prepared for manufacturing
    [Control panel.SchDoc, DETECTOR.SchDoc, LO 2.SchDoc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]
2023-09-22 Add altium with PMR radio to R124 intercom
    [Interfaces.SchDoc, MCU.SchDoc, PMR_for_R124_test.PrjPcb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]
2023-09-23 Add display board
    [Display.PcbDoc, Display.PrjPcb, Display.SchDoc]
2023-10-07 Add uswitch coder
    [Display.PcbDoc, PMR_for_R124_test.xlsx, uSwitchCoder.PcbDoc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]
2023-10-08 Add assembly for uSwitch and edit of gitignore
    [uSwitchCoder.PcbDoc]
2023-11-01 Add control software
    [PMR_for_R124 Debug.cfg]
2023-11-01 Box for PMR radio ver 1
    [Viko.SLDPRT, Viko.STL, bottom.SLDPRT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]
2023-11-09 Add redukce na box
    [Redukce.SLDPRT, Redukce.STL, bottom.SLDPRT]
2023-11-24 Add connection for R123 and add description of connectors in R123
2023-11-24 Add altium design data for new version
    [BT_Header.SchDoc, HW_Control.SchDoc, Headphone_Amplifier.SchDoc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]
2024-08-12 Zacatek verze 2
    [BT_Header.SchDoc, HW_Control.SchDoc, Headphone_Amplifier.SchDoc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]
2024-08-16 Start redesign v2
    [Microphone_Amplifier.SchDoc, PMR_for_R124_v2.PrjPcb, Radio.SchDoc]
2024-10-17 Schematic for new PMR radio finished
    [BT_Header.SchDoc, HW_Control.SchDoc, Headphone_Amplifier.SchDoc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]
2024-10-21 PCB finall
    [M12_Connector.SchDoc, MCU.SchDoc, Microphone_Amplifier.SchDoc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]
2024-11-16 Přidany vyrobní podklady + testovácí deska na PA
    [PA_test.PcbDoc, PA_test.PrjPcb, PMR_for_R124_check_v2.xlsx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]
2024-12-03 Opraven otoceny zesilovac v mikrofonu.
    [Microphone_Amplifier.SchDoc]
2024-12-03 Pridany merene data filtru na vystupech, fotly z osazeni a data pro namotani filtru
    [RF_FILTER.SchDoc]
2025-02-22 Small redesign on PCB
    [PMR_for_R124_v2.PrjPcb, RF_FILTER.SchDoc, Radio.SchDoc]
2025-02-22 Software prep for tests
    [PMR_for_R124_V2 Debug.cfg]
2026-08-03 Poznamka ke schematu. Je tam totalně blbě přizpůsobene PA
    [Power_Amplifier.SchDoc]
2026-08-05 První schemata pro SDR PMR.
    [Audio_codec.SchDoc, Headphone_Amplifier.SchDoc, M12_Connector.SchDoc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]
2026-08-06 Update SDR pmr schematic
    [Headphone_Amplifier.SchDoc, MCU.SchDoc, Power.SchDoc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]
2026-08-07 Schematic update
    [442MHz-450MHz_BPF.SchDoc, 70cm_BPF.SchDoc, Audio_codec.SchDoc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]
2026-08-09 Update sdr pmr schematic and add pdfs
    [Audio_codec.SchDoc, Headphone_Amplifier.SchDoc, M12_Connector.SchDoc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]
2026-08-11 Update schematic
    [Audio_codec.SchDoc, Headphone_Amplifier.SchDoc, M12_Connector.SchDoc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]
2026-08-12 Need LP filter modification
    [Audio_codec.SchDoc, RF_FILTER.SchDoc]
2026-08-13 Update schematic, add CB port, change TCXO
    [32MHz_clock.SchDoc, Audio_codec.SchDoc, CB_CONNECTOR.SchDoc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]
2026-08-14 Schematic sdr pmr final
    [32MHz_clock.SchDoc, Audio_codec.SchDoc, CB_CONNECTOR.SchDoc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]
2026-08-20 Korekce BOM

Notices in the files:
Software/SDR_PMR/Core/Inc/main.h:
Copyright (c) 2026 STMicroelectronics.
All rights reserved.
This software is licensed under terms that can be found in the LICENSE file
